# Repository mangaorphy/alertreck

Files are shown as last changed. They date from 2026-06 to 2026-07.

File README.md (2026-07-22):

# Alertreck

**Offline edge-AI system for anti-poaching audio detection on a Raspberry Pi 4.**
Alertreck listens continuously, detects gunshots, chainsaws, vehicles and human voices in real time,
and sends GPS-tagged alerts to rangers via GSM/SMS when a threat is confirmed; entirely offline, no
internet required.

It is also a comparative research study: **five models across four machine-learning paradigms** are
trained on the same data and benchmarked, then the best edge candidate is deployed with a live
**Grad-CAM explainability dashboard**.

<p align="center">
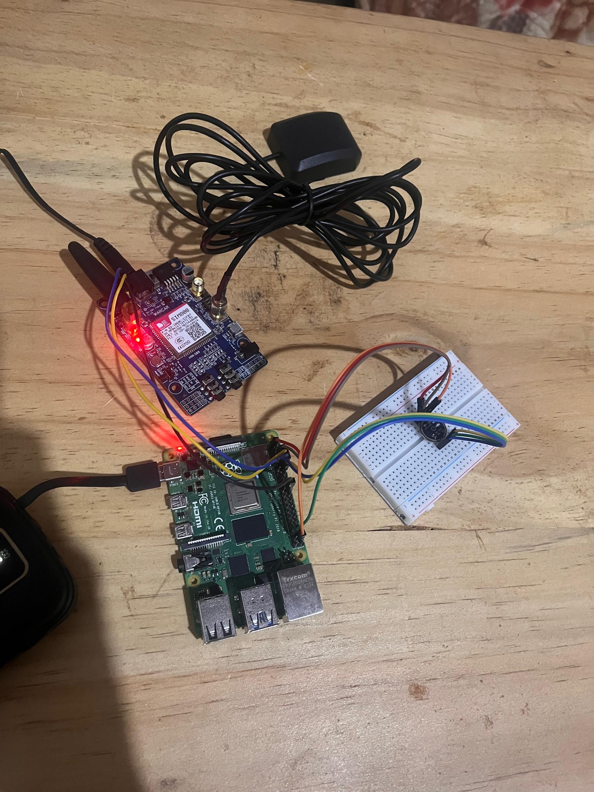
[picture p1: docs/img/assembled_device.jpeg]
Assembled Alertreck device — Raspberry Pi 4, INMP441 mic and SIM808 GSM/GPS in the enclosure
  
</p>

**Repository:** <https://github.com/mangaorphy/alertreck>

```bash
git clone https://github.com/mangaorphy/alertreck.git
```

---

## Demo Video

A full walkthrough of the system ; training, the edge device, live detection, and the Grad-CAM
dashboard:

### → **[Watch the Alertreck demo on Drive](https://drive.google.com/file/d/1CwxBU4wMTagHa2JpmVC7J57uuw0_VR09/view?usp=sharing)**

---

# Capstone Final Deliverable

> Demonstration of the planned functionalities under different testing strategies, with different data
> values, and across different hardware. Followed by analysis against the proposal, discussion of impact,
> and recommendations; prepared with supervisor **Hubert Apana**.
>
> **Jump to:** [Testing Results](#1-testing-results) · [Analysis](#2-analysis) ·
> [Discussion](#3-discussion) · [Recommendations](#4-recommendations) ·
---

## 1. Testing Results

The system was validated with three testing strategies and across two hardware tiers. Live footage of
everything below is in the **[demo video](https://drive.google.com/file/d/1CwxBU4wMTagHa2JpmVC7J57uuw0_VR09/view?usp=sharing)**.

### 1a. Functionality under different testing strategies

| Strategy | What it verifies | Artefact / command |
|---|---|---|
| **Unit testing** | Each module works in isolation ; mic capture, GPS fix, ONNX inference | `alertrack/deploy/test_i2s_mic.py`, `sensors/gps.py`, `inference/model.py` |
| **Integration testing** | Modules work together end-to-end ; capture → onset → mel → CNN → decision → SMS | `python3 -m alertrack.main` (full daemon) |
| **System / live testing** | Real acoustic events trigger real SMS alerts to a ranger phone | Live demo (video), dashboard at `:8000` |
| **Edge-case testing** | Behaviour at the margins ; low-SNR gunshot, pure background (no false alarm) | Live demo, Slide 9 of the demo script |

**Unit test ; microphone capture**

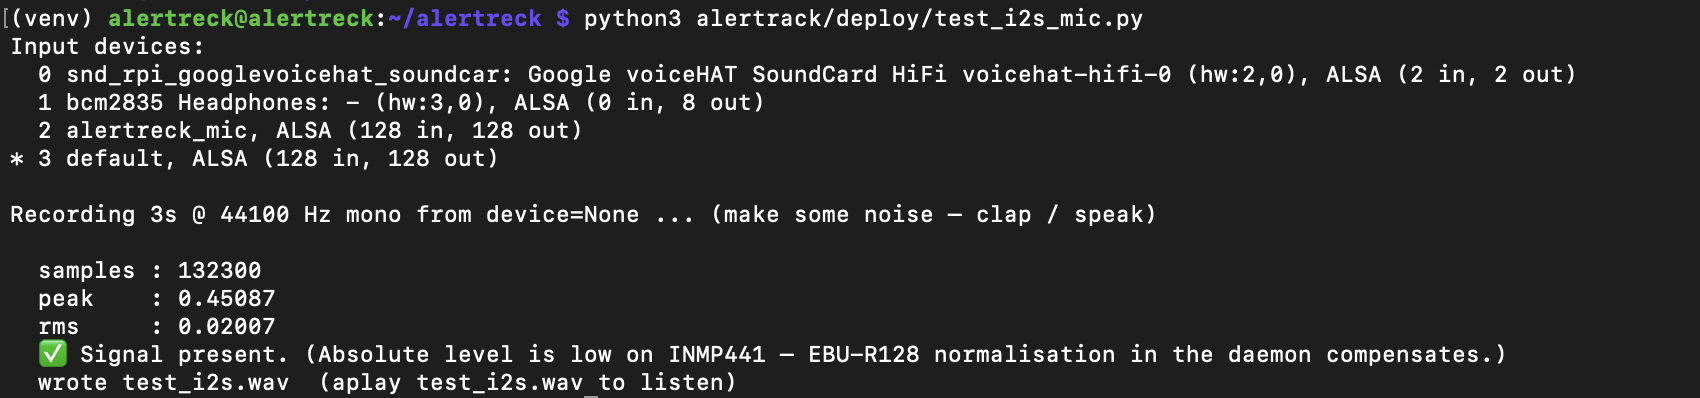
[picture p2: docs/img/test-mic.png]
Unit test ; mic capture

*Capture: terminal output of the I2S mic test showing `[PASS]` device + non-zero RMS rising on a clap vs near-zero on silence.*

**Integration test ; daemon startup + onset loop**

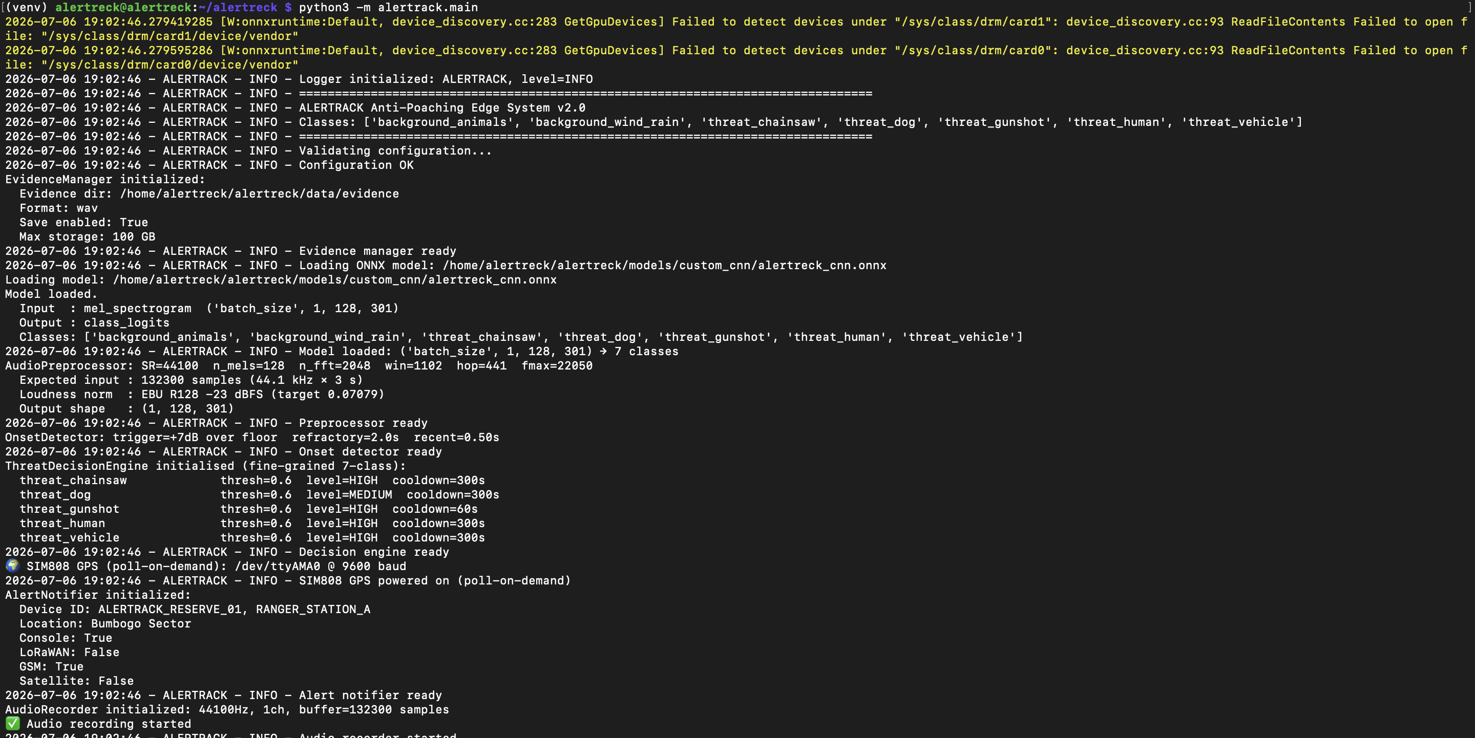
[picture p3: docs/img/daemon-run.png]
Daemon integration run

*Capture: `python3 -m alertrack.main` startup log (model loaded, onset detector ready, "System ready") followed by onset lines with non-zero RMS.*

**System test ; live threat → SMS**

<p align="center">
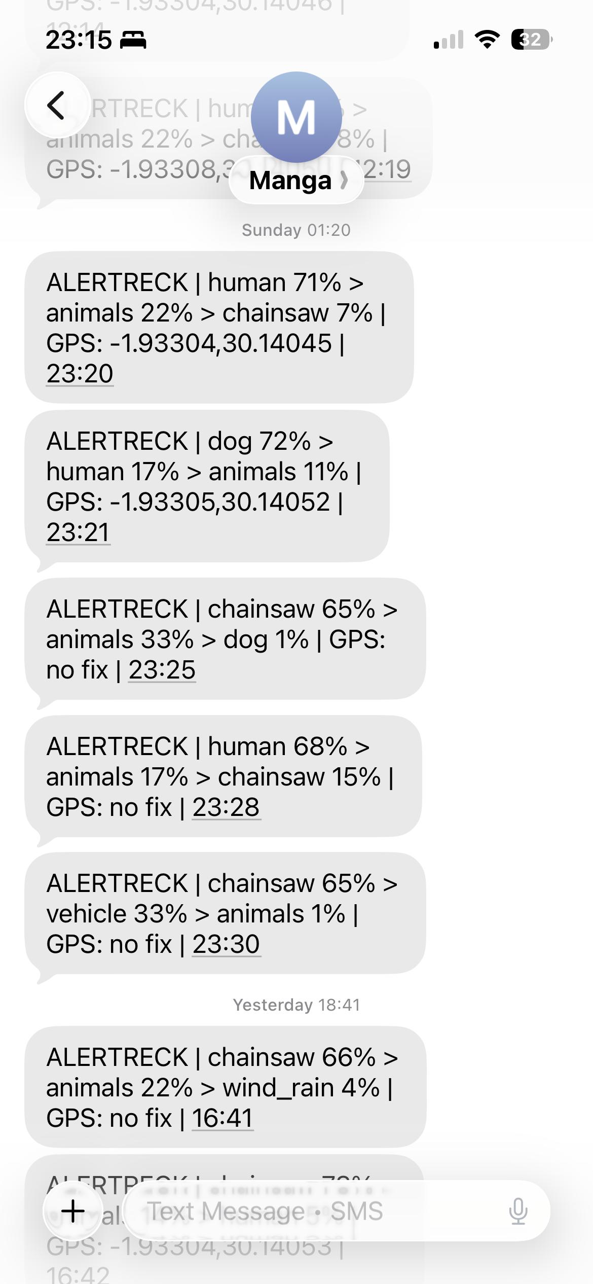
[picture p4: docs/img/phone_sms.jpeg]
Ranger phone receiving a GPS-tagged threat SMS alert from Alertreck
  
</p>

*A detected threat fires a GPS-tagged SMS to the ranger phone within seconds — class, confidence, coordinates, and timestamp.*

### 1b. Functionality with different data values

The model was exercised across **all 7 classes** ; the two background classes (must stay silent) and the
five threat classes (must each fire an independent, correctly-labelled alert).

| Input class | Expected behaviour | Result |
|---|---|---|
| `background_animals` | No alert | ignored |
| `background_wind_rain` | No alert | ignored |
| `threat_gunshot` | HIGH alert + SMS | fired (conf ≈ 0.87) |
| `threat_chainsaw` | HIGH alert + SMS | fired (conf ≈ 0.82) |
| `threat_human` | HIGH alert + SMS |fired (conf ≈ 0.91) |
| `threat_dog` | MEDIUM alert + SMS | fired |
| `threat_vehicle` | HIGH alert + SMS | weakest class (see Analysis) |

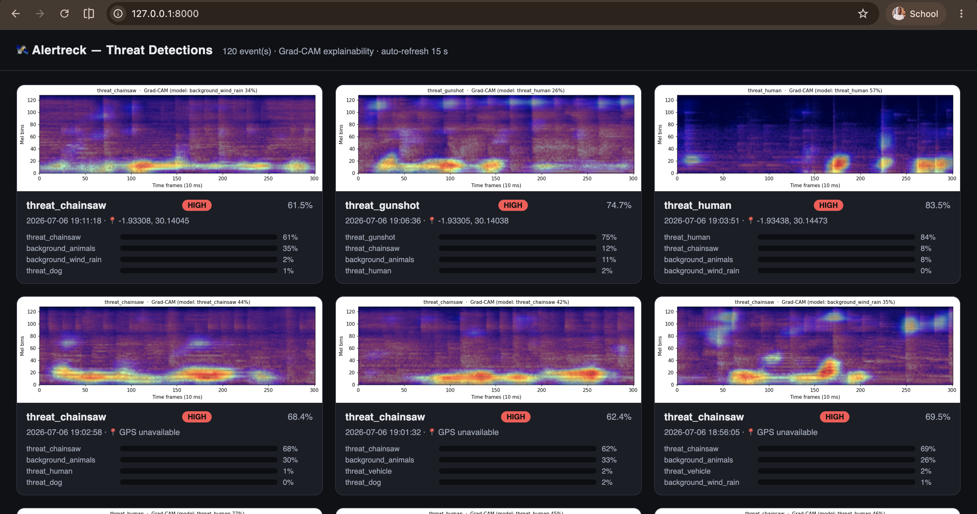
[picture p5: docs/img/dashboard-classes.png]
Dashboard ; multiple classes detected


*Different confidence values:* the decision engine applies a per-class threshold (0.60) ; clips below it
are suppressed, demonstrating the system responds to the **value** of the confidence, not just the class.

### 1c. Performance on different hardware / software

The same 4.6 MB ONNX graph trains on a cloud GPU and runs unmodified on the Pi 4 CPU.

| Metric | Training tier | Edge tier |
|---|---|---|
| Hardware | Kaggle **T4 GPU** | **Raspberry Pi 4** (4 GB), CPU-only |
| Software | Python 3.10, PyTorch 2.x, CUDA | Python 3, ONNX Runtime (no torch) |
| Role | ~4 h / model training | Real-time inference, ≤ 5 W |
| Model | PyTorch checkpoint | 4.6 MB ONNX (single graph) |
| Inference time | ; | **≤ 80 ms / 3 s window** (≈ real-time headroom) |

---

## 2. Analysis

*How the results measured against the objectives in the project proposal (with supervisor).*

### Research questions vs. outcomes

| RQ | Objective | Target | Achieved | Met? |
|---|---|---|---|---|
| **RQ1** | Edge CNN classifies 7 classes in real time on Pi 4 | usable macro-F1, real-time | Macro-F1 **0.807**, ≤80 ms, Pi 4 CPU | ✅ |
| **RQ2** | Few-shot ProtoNet matches supervised CNN | within noise | 0.804 vs 0.807 (Δ 0.003) | ✅tied |
| **RQ3** | Unsupervised anomaly detection flags threats without labels | useful AUC | Conv-AE AUC **0.805** | ⚠️ partial |
| **RQ4** | Detections are explainable | physically-plausible attribution | Grad-CAM on impulsive onset | ✅ |
| **RQ5** | Frozen W2V2 transfer beats task-trained CNN | W2V2 > CNN | 0.763 vs 0.807 | ❌ not supported |

### Per-class F1 (deployed CNN) ; against the 0.80 target

| Class | F1 | vs target |
|---|---|---|
| `threat_human` | 0.868 | ;✅ |
| `threat_chainsaw` | 0.824 | ;✅ |
| `threat_gunshot` | 0.815 | ;✅ |
| `background_*` | 0.830 | ;✅ low false-alarm rate |
| `threat_dog` | 0.794 | ⚠️ just under |
| `threat_vehicle` | 0.681 | ❌ missed (smallest class) |

### Objectives met / missed

- **Met:** real-time offline 7-class detection on a Pi 4; GPS-tagged SMS alerting; five-model
  comparison across four paradigms; live Grad-CAM explainability; gunshot (the priority threat)
  reliably detected (AUC ≈ 0.97).
- **Missed / partial:** **vehicle** F1 (0.681 vs 0.80 target) ; but its AUC is 0.97, so the class *is*
  separable and the gap is a **threshold-tuning** problem, not a modelling failure. 
- **Integrity note:** an earlier file-level split inflated every score to ≈ 0.92 via data leakage. After
  fixing it to a **group-aware split** (segments of one recording never span train/test), the honest
  numbers above are what is report.

---

## 3. Discussion

### Significance of the Milestones and Research Outcomes

This project demonstrates the feasibility of an affordable, offline edge-AI system for wildlife anti-poaching surveillance.Despite lower performance on vehicle sounds, the system achieved excellent discrimination for gunshots (AUC ≈ 0.97), the highest-priority threat class.

Several development milestones were fundamental to the validity and deployment of the system. Correcting data leakage during dataset preparation was the most significant milestone, ensuring that reported performance accurately reflected the model's generalisation ability. Implementing onset-triggered inference enabled continuous monitoring while maintaining low computational and power requirements, making long-term deployment on a Raspberry Pi practical. Exporting the model to ONNX further enabled seamless deployment from cloud-based training to edge-device inference without modification.

From a research perspective, the findings provide an important negative result. Contrary to the initial hypothesis, frozen Wav2Vec2 transfer learning did not outperform the task-specific CNN. Instead, the lightweight CNN achieved superior performance while requiring substantially fewer computational resources, suggesting that carefully trained compact models remain highly competitive for environmental threat detection.

From an engineering perspective, the comparable performance of the CNN and ProtoNet indicates that deployment decisions can be guided by computational efficiency rather than predictive accuracy alone. Given its small footprint (approximately 4.6 MB), self-contained architecture, and ease of deployment, the CNN represents the most practical solution for real-world edge-AI wildlife monitoring.

---

## 4. Recommendations

### Future Work and Practical Deployment

Several improvements can further enhance the performance and deployability of the proposed system. First, post-hoc threshold calibration should be performed for the vehicle class, as its high AUC (≈ 0.97) suggests that improved decision boundaries could increase classification performance without retraining the model. Second, the vehicle class should be expanded by collecting at least 1,000 additional audio samples to improve class balance and model generalisation.

From a deployment perspective, applying INT8 quantisation would reduce the model size from approximately 4.6 MB to 1.2 MB, enabling deployment on lower-cost hardware such as the Raspberry Pi Zero 2 W. For operational security, SMS alerts should be encrypted using secure communication protocols (e.g., AES-256 or DTLS) to protect sensitive GPS coordinates from interception. In addition, integrating solar power and supercapacitor-based energy storage would enable reliable long-term operation in remote, off-grid environments.

Finally, the system should be deployed through a community-centred model by publishing the hardware bill of materials (BOM), deployment guide, and maintenance procedures. This would facilitate replication by wildlife reserves and conservation organisations seeking an affordable, offline edge-AI solution for anti-poaching surveillance.

---

## Data, Dataset & Models

The raw audio, processed feature shards, and trained model artifacts are **too large for git** and live
in Google Drive:

### → **[Alertreck Data, Dataset & Models (Google Drive)](https://drive.google.com/drive/folders/1U9BwIUNQ8Snl5RxR8LHthWfdOc_EdcTM?usp=sharing)**

| Folder | Place into | Contents |
|---|---|---|
| `dataset/` | `./dataset/` | Raw audio, 7 class folders (11,333 files) |
| `data/processed/` | `./data/processed/` | Mel / MFCC shards, W2V2 embeddings, `splits.json`, `manifest.json` |
| `models/` | `./models/` | Trained checkpoints, ONNX exports, `results.json` per model |

Download these and drop them into the matching paths at the repo root to run training, evaluation, the
report notebook, or the dashboard.

---

## Overview

| Paradigm | Model | Notebook | Role |
|---|---|---|---|
| Supervised classification | Custom CNN | `03a-train-cnn` | **Deployed** (edge) |
| Few-shot metric learning | Prototypical Network | `03b-train-protonet` | Accuracy benchmark |
| Transfer learning (frozen) | Wav2Vec2-L2 | `04a-train-w2v2-l2` | Benchmark |
| Unsupervised anomaly detection | Convolutional Autoencoder | `04b-train-conv-ae` | Anomaly detector (best of the two) |
| Classical anomaly detection | One-Class SVM | `04c-train-oc-svm` | Confirmatory (lightest) |

---

## Hardware

| Component | Spec |
|---|---|
| Edge device | Raspberry Pi 4 (4 GB) |
| Microphone | INMP441 I2S MEMS mic (digital, no analog hum) |
| Alert module | SIM808 GSM/GPS over UART |
| Deployment | Offline-first; SMS/GPRS alert with GPS coordinates |

### System architecture

<p align="center">
  Alertreck system architecture — audio capture, onset detection, CNN inference, decision engine, and GSM/GPS alerting
</p>

---

## Dataset

7 audio classes, 44.1 kHz. Raw clips are **variable length** (~0.6–12 s, median ≈ 5 s) — impulsive
classes (gunshot, dog) are short, continuous classes (chainsaw, wind/rain) are longer. During
preprocessing every clip is standardized into **3-second analysis windows** (44.1 kHz mono) for both
training and edge inference. Background classes never alert; threat classes (2–6) trigger alerts.

| Label | Class | Category | Raw files | Audio (hrs) |
|---|---|---|---|---|
| 0 | `background_animals` | Background | 2,139 | 3.66 |
| 1 | `background_wind_rain` | Background | 2,000 | 4.58 |
| 2 | `threat_chainsaw` | Threat | 568 | 1.43 |
| 3 | `threat_dog` | Threat | 1,040 | 0.93 |
| 4 | `threat_gunshot` | Threat | 3,304 | 3.38 |
| 5 | `threat_human` | Threat | 1,242 | 2.33 |
| 6 | `threat_vehicle` | Threat | 1,040 | 1.15 |
| | **Total** | | **11,333** | **≈ 17.5** |

*Total ≈ **17.5 hours** of raw audio. Durations measured with `soundfile`; 33 corrupt/unreadable files
(all `threat_chainsaw`) are excluded from the hour totals.*

Feature extraction, the group-aware 60/20/20 split (split by parent recording to prevent leakage), and
the three-phase augmentation curriculum are documented in
**[docs/AUDIO_PREPROCESSING.md](docs/AUDIO_PREPROCESSING.md)**.

---

## Project Structure

```
alertreck/
├── dataset/                       # Raw audio (7 class folders)            ── from Drive
├── data/processed/                # Mel/MFCC shards, W2V2 embeddings        ── from Drive
│   ├── mel/   {train, val, test, train_aug_A/B/C}/  shard_NNN.npz
│   ├── mfcc/  {same}/                                shard_NNN.npz
│   ├── w2v2_l2/                    # 768-dim L2-normalised embeddings
│   ├── splits.json                # Group-aware 60/20/20 by parent recording (seed 42)
│   └── manifest.json              # Full run parameters + script SHA256
├── notebooks/
│   ├── 00-model-report.ipynb      # Consolidated report: data viz + all metrics + Grad-CAM
│   ├── 02b-prepare-w2v2-embeddings.ipynb
│   ├── 03a-train-cnn.ipynb        ├ 03b-train-protonet.ipynb
│   ├── 04a-train-w2v2-l2.ipynb    ├ 04b-train-conv-ae.ipynb
│   └── 04c-train-oc-svm.ipynb
├── scripts/
│   ├── audio_preprocessing.py     # Mel/MFCC shards + augmentation curriculum
│   ├── prepare_w2v2_embeddings.py # W2V2 embedding extraction
│   ├── export_model.py            # PyTorch → ONNX (CNN, 301-frame, dynamic width)
│   ├── data_manifest.py  ├ data_loader.py
├── models/                        # Checkpoints, ONNX, results.json         ── from Drive
│   └── {custom_cnn, protonet, w2v2_l2, conv_ae, oc_svm}/
├── alertrack/                     # Raspberry Pi edge service
│   ├── main.py                    # Onset-triggered inference loop
│   ├── audio/{recorder,preprocess,onset}.py
│   ├── inference/{model,decision}.py
│   ├── sensors/gps.py  ├ alerts/notifier.py  ├ storage/{evidence,logger}.py
│   ├── config.py  └ alertrack.service        # systemd unit
├── dashboard/                     # Grad-CAM explainability dashboard (Flask, runs on a Mac)
│   ├── app.py  ├ gradcam.py  ├ templates/index.html
│   ├── sync_events.sh  └ README.md
├── docs/                          # Full documentation (see below)
└── README.md
```

---

## Pipeline

### 1. Preprocess (local)
```bash
python3 scripts/audio_preprocessing.py --aug-phase A B C
```
Writes mel + MFCC shards to `data/processed/`. Upload to Kaggle as `alertreck-mel2` / `alertreck-mfcc`.

### 2. W2V2 embeddings (Kaggle GPU, ~2 h)
Run `02b-prepare-w2v2-embeddings.ipynb`; upload the output as the `w2v2-embeddings` dataset.

### 3. Train (Kaggle GPU)
Run `03a → 03b → 04a → 04b → 04c`. Each saves `results.json` + an ONNX/joblib model.

### 4. Export for the edge
```bash
/opt/anaconda3/bin/python scripts/export_model.py \
  --model models/custom_cnn/best_model.pt --out models/custom_cnn/alertreck_cnn.onnx
```

### 5. Deploy to the Pi
Full runbook ; flashing, mic calibration, onset tuning, GSM/GPS ; in
**[docs/DEPLOYMENT.md](docs/DEPLOYMENT.md)**.

---

## Results

Numbers below are on the **leak-free group-aware split** (an earlier file-level split inflated every
score to ≈ 0.92; those figures are retired).

| Model | Test Acc | Macro F1 | AUC | Gunshot | Edge-ready |
|---|---|---|---|---|---|
| **CNN (deployed)** | **0.8263** | **0.8069** | **0.9757** | F1 0.815 | ;✅ **best** |
| ProtoNet | 0.8241 | 0.8036 | 0.9748 | F1 **0.843** | ;✅ |
| Wav2Vec2-L2 | 0.7806 | 0.7626 | 0.9605 | F1 0.812 | ⚠️ (truncated encoder) |
| Conv-AE (binary) | 0.51 | ; | **0.8050** | AUC **0.839** | ⚠️ |
| OC-SVM (binary) | 0.51 | ; | 0.7192 | AUC 0.627 | ; |

The two task-trained classifiers (**CNN ≈ ProtoNet**) are statistically tied at the top; the
frozen-transfer **Wav2Vec2-L2** trails ; the RQ5 result that out-of-species transfer extends to threat
sounds but does not overtake supervised learning. The **CNN is both the most accurate and the deployed
model** (smallest, self-contained, real-time on a Pi 4 CPU). **Vehicle** is the hardest class; gunshot
is reliably detected (AUC ≈ 0.97) by all three. Among the anomaly detectors the AUC-selected **Conv-AE**
(binary AUC 0.805) beats the classical **OC-SVM** (0.719) ; though OC-SVM is far lighter. Full
analysis: **[docs/MODEL_COMPARISON.md](docs/MODEL_COMPARISON.md)**.

**[notebooks/00-model-report.ipynb](notebooks/00-model-report.ipynb)** ; class
distributions, all-model metrics, and Grad-CAM.

---

## Edge System (`alertrack/`)

The deployed daemon runs a fast ONNX CNN with field-hardened audio handling:

- **Onset-triggered inference** ; classifies the 3 s window around a detected energy onset (adaptive
  noise floor), instead of a blind timer: fewer false positives, less CPU, event centred in the window.
- **Train/serve-consistent preprocessing** ; EBU R128 loudness + `win_length=1102` + 301 frames,
  matching training exactly. (A 50/60 Hz mains-hum high-pass remains from the USB-mic era; the INMP441
  I2S mic is digital and carries no analog hum, so it is now largely redundant.)
- **Decision engine** ; per-class thresholds, alert levels (HIGH/MEDIUM), independent cooldowns.
- **Alerting** ; SIM808 GSM/SMS with GPS coordinates; audio + metadata evidence saved per detection.
- **Resilience** ; `systemd` auto-restart, mic/GPS reconnect, storage limits.

---

## Explainability Dashboard (`dashboard/`)

A Flask LAN dashboard showing each detected sound with a **Grad-CAM** heatmap over its mel spectrogram ;
*why* the CNN flagged it. Runs on a separate machine where PyTorch lives, so the Pi stays
ONNX-only; it auto-syncs detections from the Pi and refreshes itself. See
**[dashboard/README.md](dashboard/README.md)**.

```bash
cd dashboard && /opt/anaconda3/bin/python app.py    # → http://<mac-ip>:8000
```

---

## Documentation

- [ROADMAP.md](docs/ROADMAP.md) ; milestones and research questions
- [Alertreck_Proposal_Updated.pdf](Alertreck_Proposal_Updated.pdf) ;  project proposal
- [DESIGN.md](docs/DESIGN.md) ; system architecture
- [MODEL_DESIGN.md](docs/MODEL_DESIGN.md) ; model specifications
- [AUDIO_PREPROCESSING.md](docs/AUDIO_PREPROCESSING.md) ; feature extraction + augmentation curriculum
- [MODEL_COMPARISON.md](docs/MODEL_COMPARISON.md) ; comparative results and model selection
- [DEPLOYMENT.md](docs/DEPLOYMENT.md) ; Raspberry Pi deployment runbook
- [dashboard/README.md](dashboard/README.md) ; Grad-CAM dashboard

---

## Requirements

Training runs on Kaggle (Python 3.10, PyTorch 2.x, CUDA). Edge inference runs on a Raspberry Pi 4 with
ONNX Runtime (CPU) ; no torch on the Pi. The Grad-CAM dashboard needs torch, on the Mac only.

```
# Training / dashboard (Mac/Kaggle):  torch transformers scikit-learn librosa soundfile
#                                      onnxruntime joblib tqdm matplotlib flask
# Edge (Raspberry Pi):                 numpy librosa sounddevice soundfile onnxruntime pyserial psutil
```

---

*Capstone project ; African Leadership University, 2025–2026.*
*Large artifacts (dataset, processed data, models): [Google Drive](https://drive.google.com/drive/folders/1U9BwIUNQ8Snl5RxR8LHthWfdOc_EdcTM?usp=sharing).*

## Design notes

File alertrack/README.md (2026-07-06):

# ALERTRACK - Anti-Poaching Edge System

**Offline-first, AI-powered threat detection system for wildlife conservation**

## 🎯 Overview

ALERTRACK is a production-ready edge ML system designed to run 24/7 on Raspberry Pi devices in remote wildlife areas. It uses audio classification to detect poaching threats (gunshots, chainsaws, vehicles) in real-time and triggers immediate alerts.

### Key Features

- ✅ **Fully Offline**: No internet required - runs completely on device
- ✅ **Real-time Detection**: Continuous audio monitoring with rolling buffer
- ✅ **High Accuracy**: deployed CNN — 0.826 test accuracy / 0.807 macro-F1 (leak-free group-aware split)
- ✅ **Fault Tolerant**: Auto-reconnect on hardware failures, never crashes
- ✅ **GPS Integration**: Precise threat location for rapid response
- ✅ **Evidence Collection**: Saves audio clips for retraining and verification
- ✅ **Smart Cooldown**: Prevents alert spam while maintaining sensitivity
- ✅ **Multi-channel Alerts**: Console, disk, LoRaWAN, GSM, Satellite (extensible)

## 📊 Threat Classification

| Class | Type | Threshold | Examples |
|---|---|---|---|
| **THREAT** | High Priority | ≥ 85% | Gunshot, Chainsaw, Vehicle Engine, Human Voice |
| **THREAT_CONTEXT** | Medium Priority | ≥ 75% | Dog Bark |
| **BACKGROUND** | No Alert | N/A | Animal Sounds, Wind/Rain, Ambient Noise |

## 🛠️ Hardware

### Prototype BOM (≤ USD 80)
- **Raspberry Pi 4 Model B** — 2 GB RAM, quad-core ARM Cortex-A72 @ 1.8 GHz; edge AI inference + alert dispatch
- **INMP441 I2S MEMS microphone** — digital I2S (no analog hum), 60 Hz–15 kHz; captured at 48 kHz and resampled to 44.1 kHz. Wiring + ALSA setup: [deploy/INMP441_SETUP.md](deploy/INMP441_SETUP.md)
- **SIM808 GSM/GPRS/GPS module** — UART serial, built-in GPS receiver; SMS alerts (MTN/Airtel Rwanda) + device GPS coordinates; no data plan required
- **32 GB Class 10 MicroSD card** — OS, model weights, SQLite event database, evidence audio
- **Rwanda SIM card** (MTN or Airtel) — prepaid, GSM only; inserted into SIM808

### Optional Upgrades
- **Solar panel + LiPo battery** (for remote off-grid deployment)
- **Weatherproof enclosure** (IP65+, outdoor mounting)
- **Camera module** (visual verification — stub implemented)

## 📁 Project Structure

```
alertrack/
├── main.py                 # Main entry point and system integration
├── config.py               # Central configuration
├── utils.py                # Common utilities
├── requirements.txt        # Python dependencies
├── README.md              # This file
│
├── audio/                 # Audio processing
│   ├── recorder.py        # Continuous audio capture with rolling buffer
│   └── preprocess.py      # Mel spectrogram generation
│
├── inference/             # Machine learning
│   ├── model.py          # TFLite model loading and inference
│   └── decision.py       # Threat thresholding and cooldown logic
│
├── sensors/              # Hardware sensors
│   └── gps.py           # GPS coordinate reading (NMEA parsing)
│
├── alerts/               # Notification system
│   └── notifier.py      # Multi-channel alert dispatch
│
└── storage/              # Data persistence
    ├── logger.py         # System logging with rotation
    └── evidence.py       # Audio evidence storage and management
```

## 🚀 Installation

### 1. Prepare Raspberry Pi

```bash
# Update system
sudo apt update && sudo apt upgrade -y

# Install system dependencies
sudo apt install -y python3-pip python3-venv portaudio19-dev libsndfile1

# Install optional tools
sudo apt install -y git vim htop
```

### 2. Clone/Copy Project

```bash
# Copy project to Raspberry Pi
scp -r alertrack/ pi@raspberrypi.local:~/

# Or clone from repository
git clone <your-repo-url> ~/alertrack
cd ~/alertrack
```

### 3. Create Virtual Environment

```bash
cd ~/alertrack
python3 -m venv venv
source venv/bin/activate
```

### 4. Install Python Dependencies

```bash
# Install TFLite Runtime (Raspberry Pi optimized)
pip install --index-url https://google-coral.github.io/py-repo/ tflite_runtime

# Install other dependencies
pip install -r requirements.txt
```

### 5. Add Model Files

```bash
# Create models directory
mkdir -p models

# Copy your trained .tflite model
# Example: yamnet_classifier.tflite, threat_detection_custom_cnn.tflite, etc.
scp your_model.tflite pi@raspberrypi.local:~/alertrack/models/
```

### 6. Configure GPS (if using)

```bash
# Find GPS device
ls /dev/ttyUSB* /dev/ttyACM*

# Test GPS connection
cat /dev/ttyUSB0  # Should see NMEA sentences ($GPGGA, $GPRMC, etc.)

# Edit config.py to set correct GPS port
nano config.py
# Set: GPS_PORT = "/dev/ttyUSB0"
```

## ⚙️ Configuration

Edit [config.py](config.py) to customize:

```python
# Model selection
MODEL_PATH = "models/yamnet_classifier.tflite"  # or custom_cnn, mobilenet

# Device identification
DEVICE_ID = "ALERTRACK-001"
DEVICE_LOCATION = "Serengeti National Park, Zone A"

# Threat thresholds
THREAT_THRESHOLD = 0.85          # 85% confidence for THREAT
THREAT_CONTEXT_THRESHOLD = 0.75  # 75% for THREAT_CONTEXT

# Cooldown (prevent alert spam)
COOLDOWN_SECONDS = 300  # 5 minutes per threat type

# GPS
ENABLE_GPS = True
GPS_PORT = "/dev/ttyUSB0"
SIMULATE_GPS = False  # Set True for testing without GPS hardware

# Storage limits
MAX_EVIDENCE_STORAGE_GB = 100  # Auto-cleanup when exceeded
ALERT_RETENTION_DAYS = 90      # Delete evidence older than 90 days
```

## 🎮 Running the System

### Manual Start (Testing)

```bash
cd ~/alertrack
source venv/bin/activate
python main.py
```

### Auto-start on Boot (Production)

```bash
# Copy systemd service file
sudo cp alertrack.service /etc/systemd/system/

# Edit service to set correct paths
sudo nano /etc/systemd/system/alertrack.service

# Enable and start service
sudo systemctl enable alertrack.service
sudo systemctl start alertrack.service

# Check status
sudo systemctl status alertrack.service

# View logs
sudo journalctl -u alertrack -f
```

### Stop the System

```bash
# If running manually: Ctrl+C

# If running as service:
sudo systemctl stop alertrack.service
```

## 📋 System Logs

Logs are saved to `logs/alertrack.log` with automatic rotation (10 MB max, 5 backups).

```bash
# View live logs
tail -f logs/alertrack.log

# View service logs
sudo journalctl -u alertrack -f
```

## 🚨 Alerts

Alerts are saved to `alerts/` directory as JSON files:

```json
{
  "alert_id": "abc123...",
  "timestamp": "2024-01-15T14:30:45Z",
  "device_id": "ALERTRACK-001",
  "threat_type": "gunshot",
  "threat_level": "HIGH",
  "confidence": 0.94,
  "latitude": -2.1534,
  "longitude": 34.6857,
  "audio_evidence": "evidence/2024-01-15/gunshot/gunshot_143045.wav"
}
```

## 📦 Evidence Storage

Audio clips are organized by date and threat type:

```
evidence/
├── 2024-01-15/
│   ├── gunshot/
│   │   ├── gunshot_143045.wav
│   │   └── gunshot_151230.wav
│   └── chainsaw/
│       └── chainsaw_160015.wav
└── 2024-01-16/
    └── vehicle_engine/
        └── vehicle_160530.wav
```

## 🧪 Testing Individual Modules

Each module includes standalone test functions:

```bash
# Test audio recorder
python -m audio.recorder

# Test GPS reader
python -m sensors.gps

# Test model inference
python -m inference.model

# Test preprocessor
python -m audio.preprocess
```

## 🔧 Troubleshooting

### Audio Issues

```bash
# List available microphones
python -c "import sounddevice as sd; print(sd.query_devices())"

# Test microphone
arecord -l  # List devices
arecord -D plughw:1,0 -d 5 test.wav  # Record 5 seconds
aplay test.wav  # Playback
```

### GPS Issues

```bash
# Check GPS device connection
ls /dev/ttyUSB* /dev/ttyACM*

# Read raw NMEA sentences
cat /dev/ttyUSB0

# Check permissions
sudo usermod -a -G dialout $USER
# Logout and login again

# Test with simulation mode
# In config.py: SIMULATE_GPS = True
```

### Model Issues

```bash
# Verify model file exists
ls -lh models/*.tflite

# Test model loading
python -c "from inference.model import TFLiteModel; m = TFLiteModel('models/your_model.tflite'); print(m.get_model_info())"
```

### Performance Issues

```bash
# Check CPU/Memory usage
htop

# Monitor inference time (should be < 2 seconds)
# Watch logs for warnings: "Inference took X.XXs"

# Reduce inference frequency if needed
# In config.py: INFERENCE_INTERVAL = 5.0  # seconds
```

## 📊 Performance Metrics

- **Inference Time**: ~0.5-1.5s on Raspberry Pi 4 (TFLite optimized)
- **Memory Usage**: ~300-500 MB
- **CPU Usage**: ~30-50% (single core)
- **Storage**: ~10-50 MB per day (depends on threat frequency)

## 🔐 Security Considerations

- **Offline Operation**: No network connectivity required (prevents hacking)
- **Evidence Integrity**: WAV files saved with timestamps and metadata
- **Access Control**: Run as non-root user, use systemd for isolation
- **Data Retention**: Automatic cleanup prevents disk overflow

## 🛣️ Roadmap

- [x] Core audio classification pipeline
- [x] GPS integration
- [x] Evidence storage and management
- [x] Cooldown logic
- [ ] LoRaWAN alert transmission
- [ ] GSM/SMS alert transmission
- [ ] Satellite communication (Iridium, Globalstar)
- [ ] Camera integration for visual verification
- [ ] Multi-device mesh network
- [ ] Web dashboard for fleet management

## 📄 License

[Your License Here]

## 🤝 Contributing

[Your Contribution Guidelines]

## 📞 Support

For issues or questions:
- Email: [your-email]
- GitHub Issues: [your-repo-url]

---

**Built with ❤️ for wildlife conservation**

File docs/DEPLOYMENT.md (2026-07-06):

# ALERTRACK  Raspberry Pi Deployment Guide

---

## Part 1  Flash a Fresh SD Card

**On your Mac:**

1. Download **Raspberry Pi Imager** from [raspberrypi.com/software](https://www.raspberrypi.com/software/)
2. Insert SD card (16 GB minimum, 32 GB recommended)
3. Open Imager → **Choose OS** → `Raspberry Pi OS Lite (64-bit)` (no desktop needed)
4. **Before writing**  click the gear icon (⚙️) and configure:
   - Enable SSH ✓
   - Set username: `alertreck` / password: (your choice  avoid special characters)
   - Set Wi-Fi SSID + password (your hotspot or router)
   - **Set Wi-Fi country** (e.g. `RW`)  without it the radio stays disabled and the Pi never joins
   - Set hostname: `alertreck`
5. Click **Write** and wait

---

## Part 2  Find the Pi's IP Address

After inserting the SD card and booting the Pi, wait ~60 seconds then try one of these:

**Option A  mDNS hostname (easiest):**
```bash
ping alertreck.local
```
The IP will show in the response, e.g. `64 bytes from 192.168.1.88`

**Option B  Scan the network:**
```bash
# Install nmap if needed: brew install nmap
nmap -sn 192.168.1.0/24 | grep -i raspberry
```
> Replace `192.168.1` with your actual prefix. Check yours with: `ipconfig getifaddr en0`

**Option C  From your router:**
Log into your router admin page (usually `192.168.1.1`) → connected devices → look for `alertreck`

**Option D  Connect a monitor and run:**
```bash
hostname -I
```

---

## Part 3  SSH into the Pi

```bash
ssh alertreck@alertreck.local
# or use the IP directly (changes on DHCP reboot  prefer the hostname above)
ssh alertreck@192.168.1.88
```

**First connection only**  type `yes` when asked about authenticity.

Username: `alertreck`  ·  Password: whatever you set in the Imager.

> Modern Raspberry Pi OS (Bookworm) has **no default `pi` user**  the account is the username
> you set when flashing. If SSH says "Permission denied", you are almost certainly using the wrong
> username (not the wrong password); SSH prompts for a password even when the user doesn't exist.

**SSH refused?** SSH was not enabled during flashing. Fix from your Mac:
```bash
touch /Volumes/bootfs/ssh
```
Eject, reinsert SD card into Pi, reboot.

**Set up a `ssh alertreck` alias + passwordless login (one-time, recommended):**
```bash
# On your Mac  add the alias to ~/.ssh/config
cat >> ~/.ssh/config <<'EOF'

Host alertreck
    HostName alertreck.local
    User alertreck
    StrictHostKeyChecking accept-new
EOF

# Copy your key so you never type the password again (asks for it once)
ssh-copy-id alertreck
ssh alertreck 'echo connected'    # should print "connected" with no prompt
```
> **After a reflash** the Pi gets a new SSH identity. Clear the stale key first or SSH will refuse:
> `ssh-keygen -R alertreck.local && ssh-keygen -R <old-ip>`, then `ssh-copy-id alertreck` again.

---

## Part 4  Set Up the Pi Environment

Run these commands **on the Pi** (inside the SSH session):

```bash
# Update system
sudo apt update && sudo apt upgrade -y

# Install system dependencies
sudo apt install -y python3-pip python3-venv ffmpeg git libportaudio2 libsndfile1

# Create project folder
mkdir -p ~/alertreck/models/custom_cnn
cd ~/alertreck

# Create Python virtual environment
python3 -m venv venv
source venv/bin/activate

# Install Python dependencies
pip install numpy librosa sounddevice soundfile onnxruntime pyserial psutil
```

---

## Part 5  Export & Deploy the Model

**On your Mac**, run from inside the `alertreck` project folder.

>**Don't have the trained model?** The checkpoints, ONNX exports, and `results.json` are on
> Google Drive: [Alertreck Data, Dataset & Models](https://drive.google.com/drive/folders/1U9BwIUNQ8Snl5RxR8LHthWfdOc_EdcTM?usp=sharing).
> Download `models/custom_cnn/` to skip training and go straight to deployment.

> **Environment:** the export needs `torch` + `onnx` + `onnxruntime`. These live in the **base**
> conda env (`/opt/anaconda3/bin/python`), *not* the `alertreck` env (which only has the runtime
> deps librosa/numpy). Use the base interpreter for export.
>
> **Checkpoint path:** the trained checkpoint is `models/custom_cnn/best_model.pt`. The script
> defaults to `models/best_model.pt`, so you **must** pass `--model` explicitly or it will fail
> with "model not found".

```bash
# Step 1  Export the trained PyTorch checkpoint to ONNX (traces at 301 frames, dynamic width)
/opt/anaconda3/bin/python scripts/export_model.py \
  --model models/custom_cnn/best_model.pt \
  --out   models/custom_cnn/alertreck_cnn.onnx
# Expect: "ONNX validation OK  output shape: (1, 7)"
# Output : models/custom_cnn/alertreck_cnn.onnx
#          input mel_spec = [batch, 1, 128, frames]  (frames dynamic; training shape = 301)

# Step 2  Copy the model to the Pi
scp models/custom_cnn/alertreck_cnn.onnx alertreck@alertreck.local:~/alertreck/models/custom_cnn/

# Step 3  Copy the daemon code to the Pi
rsync -av --exclude='__pycache__' alertrack/ alertreck@alertreck.local:~/alertreck/alertrack/
```

> **Verify the export (optional but recommended)** before copying:
> ```bash
> /opt/anaconda3/bin/python -c "import onnxruntime as ort, numpy as np; \
> s=ort.InferenceSession('models/custom_cnn/alertreck_cnn.onnx'); i=s.get_inputs()[0]; \
> print(i.name, i.shape); \
> print('301 OK', s.run(None,{i.name:np.random.randn(1,1,128,301).astype(np.float32)})[0].shape)"
> ```
> Should print `mel_spec ['batch', 1, 128, 'frames']` and `301 OK (1, 7)`.

---

## Part 6  Test the System on the Pi

```bash
# SSH into the Pi
ssh alertreck@alertreck.local

cd ~/alertreck
source venv/bin/activate

# Test model loads correctly
python3 -c "from alertrack.inference.model import ONNXModel; ONNXModel()"

# Test audio preprocessor
python3 -c "from alertrack.audio.preprocess import test_preprocessor; test_preprocessor()"

# Run the full system (Ctrl+C to stop).
# Must run as a module (-m) from ~/alertreck  main.py uses package-relative imports,
# so `python3 alertrack/main.py` fails with "attempted relative import with no known parent package".
python3 -m alertrack.main
```

> Run with `ALERTRACK_DEBUG=true python3 -m alertrack.main` to print the predicted class +
> confidence and the raw RMS every inference cycle  essential for the calibration in Part 6A.

---

## Part 6A  Microphone Setup & Calibration (INMP441 I2S)

The mic is the single biggest source of wrong predictions. Alertreck uses the **INMP441 I2S MEMS**
microphone  a digital mic on the Pi's I2S bus: no USB, no analog gain control, and no mains hum.

### 1. Wire it and enable I2S
Full wiring table, `config.txt` overlay, and the ALSA config are in
**[../alertrack/deploy/INMP441_SETUP.md](../alertrack/deploy/INMP441_SETUP.md)**. In short:

- Wire VDD→3V3, GND→GND, SCK→GPIO18, WS→GPIO19, SD→GPIO20, L/R→GND (left channel). **3.3 V only.**
- Add to `/boot/firmware/config.txt`: `dtparam=i2s=on` and `dtoverlay=googlevoicehat-soundcard`, then reboot.
- `sudo cp alertrack/deploy/asound.conf /etc/asound.conf` so the mic is the ALSA **default**
  (resampled 48→44.1 kHz, downmixed to mono).
- `config.py` already has `MIC_DEVICE_INDEX = None` (use the ALSA default).

Confirm the mic card and the SIM808 UART both came up:
```bash
arecord -l            # card "sndrpigooglevoi"
ls -l /dev/ttyAMA0    # SIM808 UART
```

### 2. Verify capture and level
The INMP441 is a quiet mic  that is expected. EBU-R128 normalisation rescales loudness before the
model, so the absolute level does not need tuning (there is no gain control). Just confirm it is alive:
```bash
# on the Pi: record 5 s (clap/speak during it), then check the level
arecord -D default -f S16_LE -r 44100 -c 1 -d 5 /tmp/cal.wav
python3 alertrack/deploy/test_i2s_mic.py        # prints peak / rms, writes test_i2s.wav
```
A working mic shows `peak`/`rms` clearly rising on sound and near-zero on silence. The measured ambient
floor is ≈ 0.0003 and real events ≈ 0.02.

### 3. Onset / silence thresholds (already calibrated for the INMP441)
Because the INMP441 is quieter than the old USB mic, the absolute energy gates in `config.py` were
lowered to match its noise floor (the old `0.01` sat *above* real events on this mic and silenced them):
```python
SILENCE_THRESHOLD = 0.0015   # skip inference below this raw RMS  (floor ~= 0.0003, events ~= 0.02)
ONSET_MIN_RMS     = 0.0015   # onset never fires below this absolute floor
ONSET_TRIGGER_DB  = 7.0      # relative gate over the adaptive floor (mic-agnostic, unchanged)
```
Nudge `0.0015` up toward `0.002` if idle silence ever triggers, or down to `0.001` if faint/distant
events are missed. To recalibrate from scratch, record ~10 s of true silence and set the gate a few×
above the measured per-frame floor.

> **No mains hum.** The INMP441 is digital, so the 50/60 Hz mains hum that plagued the USB mic is gone
>  along with the USB-power-isolator / powered-hub workarounds it required. The `HPF_CUTOFF_HZ`
> high-pass in `config.py` is now largely redundant (it still harmlessly removes wind rumble); set
> `HPF_ENABLED = False` and compare field detections if you prefer.

---

## Part 7  Enable Auto-Start on Boot

The service file (`alertrack/alertrack.service`) is already configured for the `alertreck` user,
the `/home/alertreck/alertreck` project path, and the `-m alertrack.main` module entrypoint 
no editing needed. Just install and enable it:

```bash
# On the Pi  install the systemd service
sudo cp ~/alertreck/alertrack/alertrack.service /etc/systemd/system/

sudo systemctl daemon-reload
sudo systemctl enable alertrack
sudo systemctl start alertrack

# Verify it is running
sudo systemctl status alertrack
```

> If you edit the daemon code later, re-`rsync` from the Mac then
> `sudo systemctl restart alertrack`. If you change `alertrack.service` itself,
> re-copy it and run `sudo systemctl daemon-reload` before restarting.

---

## Part 8  Common Commands

| Task | Command (on Pi) |
|---|---|
| Check system status | `sudo systemctl status alertrack` |
| Watch live logs | `journalctl -u alertrack -f` |
| Restart after code update | `sudo systemctl restart alertrack` |
| Stop the system | `sudo systemctl stop alertrack` |
| Disable auto-start | `sudo systemctl disable alertrack` |

| Task | Command (on Mac) |
|---|---|
| Update model on Pi | `scp models/custom_cnn/alertreck_cnn.onnx alertreck@alertreck.local:~/alertreck/models/custom_cnn/` |
| Update daemon code | `rsync -av --exclude='__pycache__' alertrack/ alertreck@alertreck.local:~/alertreck/alertrack/` |
| Open SSH session | `ssh alertreck@alertreck.local` |

---

## Part 9  Troubleshooting

| Problem | Fix |
|---|---|
| `onnxruntime not found` | Activate venv first: `source ~/alertreck/venv/bin/activate` |
| `No module named sounddevice` | `sudo apt install -y libportaudio2` then `pip install sounddevice` |
| `Permission denied` on SSH | SSH not enabled  create empty `ssh` file on boot partition (see Part 3) |
| `Permission denied` (password rejected) | Wrong **username**  use `alertreck@…`, not `pi@…` (no default `pi` user on Bookworm) |
| Pi not found at `alertreck.local` | Find IP via `ping alertreck.local`, then: `ssh alertreck@192.168.1.88` |
| Model not found error | Re-export on Mac (see Part 5, pass `--model models/custom_cnn/best_model.pt`), then copy to Pi |
| No audio device found | I2S overlay didn't load  check `arecord -l` shows `sndrpigooglevoi`; confirm `dtparam=i2s=on` + `dtoverlay=googlevoicehat-soundcard` in `config.txt`, reboot (Part 6A) |
| Mic captures silence (peak ≈ 0) | Re-check INMP441 wiring  L/R→GND and the SD/WS/SCK pins; a loose SD wire is the usual cause (`../alertrack/deploy/INMP441_SETUP.md`) |
| Real events never trigger | INMP441 floor is low  confirm `SILENCE_THRESHOLD` / `ONSET_MIN_RMS = 0.0015` in `config.py` (Part 6A step 3) |
| `arecord` works but Python is silent | PortAudio opened the wrong device  set `MIC_DEVICE_INDEX = "googlevoicehat"` in `config.py` |

---

## Part 10  Connect the SIM808 GPS / GSM Module

The SIM808 provides **GPS coordinates** (for geotagging alerts) and **GSM SMS** (to notify rangers),
both over a single UART serial link. This part covers GPS; SMS uses the same wiring.

### 1. Wire the SIM808 to the Pi 4 GPIO

| SIM808 pin | Pi 4 pin | Notes |
|---|---|---|
| `VCC` (module power) | **External 5V / ≥2A supply**, *not* the Pi's 5V | SIM808 draws ~2A bursts when the GSM radio transmits  powering it from the Pi will brown-out and reboot the Pi |
| `GND` | Pi GND (pin 6) **and** the external supply GND | Common ground is required |
| `TXD` | Pi `GPIO15 / RXD` (pin 10) | SIM808 TX → Pi RX |
| `RXD` | Pi `GPIO14 / TXD` (pin 8) | SIM808 RX → Pi TX |

Attach the **GPS antenna** (the active patch antenna) and place it with a clear view of the sky 
GPS will not get a fix indoors.

### 2. Enable the Pi's UART

The default `/dev/ttyAMA0` (PL011) on a Pi 4 is used by Bluetooth and the serial login console. Free it:
```bash
sudo raspi-config
#  Interface Options → Serial Port
#    "login shell over serial?"  → NO
#    "serial port hardware enabled?" → YES
```
Then disable Bluetooth so it doesn't claim the good UART, and reboot:
```bash
echo "dtoverlay=disable-bt" | sudo tee -a /boot/firmware/config.txt
sudo systemctl disable hciuart
sudo reboot
```
After reboot the SIM808 is on `/dev/ttyAMA0` at 9600 baud  matching `SIM808_PORT` in `config.py`.

### 3. Verify the serial link and get a GPS fix

Add yourself to the `dialout` group (one-time) so you can open the port without sudo:
```bash
sudo usermod -aG dialout alertreck   # log out / back in afterwards
```
Talk to the module and power on its GPS:
```bash
# 'AT' should echo 'OK'. Then power GPS on and stream NMEA:
python3 -c "
import serial, time
s = serial.Serial('/dev/ttyAMA0', 9600, timeout=2)
for cmd in (b'AT', b'AT+CGNSPWR=1', b'AT+CGNSOUT=1'):
    s.write(cmd + b'\r\n'); time.sleep(0.5)
    print(cmd, '->', s.read(s.in_waiting or 64))
"
```
Each command should return `OK`. Once the antenna has a sky view, a fix takes **30 s – several minutes**
the first time (cold start). Test the project's reader directly:
```bash
cd ~/alertreck
python3 -m alertrack.sensors.gps      # prints coordinates once it has a fix
```

### 4. Enable GPS (and GSM) in config

Edit `alertrack/config.py` on the Pi:
```python
GPS_ENABLED = True            # was False
NOTIFY_GSM  = True            # was False  enables SMS alerts
SIM808_PORT = "/dev/ttyAMA0"  # 9600 baud
RANGER_PHONE_NUMBERS = [
    "+250795607062",          # ranger number(s) in E.164 format
]
```

**Validate the GSM link before relying on it** (run on the Pi). Registration first:
```bash
python3 -c "
import serial, time
s=serial.Serial('/dev/ttyAMA0',9600,timeout=1)
def at(c): s.reset_input_buffer(); s.write((c+'\r\n').encode()); time.sleep(1); print(c,'->',s.read(s.in_waiting or 256).decode(errors='ignore').strip())
at('ATE0'); at('AT+CSQ'); at('AT+CREG?'); at('AT+COPS?')
"
# Want: CSQ first number >=10 ; CREG: 0,1 or 0,5 (registered) ; COPS shows the carrier
```
Then send a real test SMS to the ranger via the project's own sender:
```bash
python3 -c "
from alertrack.alerts.notifier import _sim808_send_sms
print('SMS sent:', _sim808_send_sms('+250795607062','ALERTRECK test - system online','/dev/ttyAMA0',9600,15.0))
"
```
If `AT` returns nothing, swap the TX/RX wires. If SMS reboots the module, the SIM808 power supply
is too weak (add a 1000 µF cap across VBAT, or use a stronger external supply).

Restart and watch the logs for a fix:
```bash
sudo systemctl restart alertrack
journalctl -u alertrack -f
```
When the GPS has a lock, alerts change from `Location: UNKNOWN (GPS unavailable)` to real coordinates,
and an SMS is sent to each ranger number.

> **GPS/SMS share one UART.** The daemon uses the poll-on-demand `SIM808AT` reader (it opens the port
> only to read a fix, then releases it) precisely so SMS and GPS never hold `/dev/ttyAMA0` at the same
> time. Don't switch back to a continuous NMEA reader, or SMS sends will fail with "port busy".

> **Tip:** until the antenna has a clear sky view, set `SIMULATE_GPS = True` in `config.py` to test the
> alert/SMS flow with placeholder coordinates  useful for indoor bench testing.

---

## Quick Reference

```
Pi address     : alertreck.local   (current IP 192.168.1.88  DHCP, may change on reboot)
Pi hostname    : alertreck.local
SSH user       : alertreck
Project path   : /home/alertreck/alertreck/
Model path     : /home/alertreck/alertreck/models/custom_cnn/alertreck_cnn.onnx
Venv path      : /home/alertreck/alertreck/venv/
Service name   : alertrack
Mic            : INMP441 I2S MEMS (ALSA card `sndrpigooglevoi`; default via /etc/asound.conf)
SIM808 (GPS/GSM): /dev/ttyAMA0 @ 9600 baud  (UART; GPS=AT+CGNSPWR/CGNSOUT)
```

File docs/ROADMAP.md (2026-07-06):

# Alertreck — Project Roadmap

**Student:** Orpheus Mhizha Manga · **Program:** ALU BSc SE (Machine Learning), 2026 Capstone
**Supervisor:** Hubert Apana · **Contact:** o.manga@alustudent.com
**Project:** Offline edge-AI acoustic poaching-threat detection for remote African conservation parks
**Full title:** *Offline Edge AI for Anti-Poaching Acoustic Surveillance: Benchmarking Pretrained Embeddings, Metric Learning, Supervised Classification, and Anomaly Detection on Identical Field Hardware*

> **Research questions (from proposal §1.4):**
> - RQ1: Which learning paradigm — supervised classification (CNN), metric learning (ProtoNet), frozen out-of-species transfer (W2V2-L2), or unsupervised anomaly detection (Conv-AE / OC-SVM) — achieves highest AUC-ROC, per-class F1, and lowest FPR on a 7-class African savannah acoustic dataset on identical edge hardware?
> - RQ2: How does per-class detection performance differ across the five models at SNR 5 / 10 / 20 dB, and which sound class poses the greatest detection challenge under field-representative interference?
> - RQ3: Can the SIM808 GSM/GPS module acquire a GPS fix and append device coordinates to a labelled SMS alert within the 30 s end-to-end latency budget on Pi 4 hardware, and what is the typical fix-acquisition time outdoors?
> - RQ4: Do Grad-CAM heatmaps on the winning model's mel-spectrogram inputs highlight acoustically expected time-frequency regions, supporting ranger trust?
> - RQ5: Does the out-of-species embedding advantage (Geldenhuys & Niesler, 2026) — a frozen, truncated wav2vec 2.0 layer-2 embedding approaching supervised performance for elephant calls — extend to non-biological threats (gunshots, chainsaws, vehicles) in a multi-class African savannah dataset, and does it retain that advantage on edge hardware after INT8 quantisation?

---

## 1. Locked design parameters

These are fixed by the approved proposal (May 2026). Deviations require supervisor approval.

### 1.1 Seven-class acoustic threat taxonomy

| Label | Kind | Description |
|---|---|---|
| `background_animals` | background | Non-threat wildlife: birds, elephants, lions, horses, insects, frogs |
| `background_wind_rain` | background | Weather / natural ambience: rain, wind, thunderstorm, sea waves, fire |
| `threat_gunshot` | threat | Firearm discharge (rifle, shotgun) |
| `threat_chainsaw` | threat | Chainsaw running / cutting |
| `threat_vehicle` | threat | Truck / motorbike / ATV engine in park |
| `threat_human` | threat | Human voice, shouting, footsteps, machete |
| `threat_dog` | threat | Barking / howling — poacher-dog indicator |

> **Note:** `normal` class was split into `background_animals` and `background_wind_rain` (2026-04-19) for cleaner source tracking and balanced augmentation control.

### 1.2 Audio specification

| Parameter | Value | Justification |
|---|---|---|
| Sample rate | 44.1 kHz mono | Captures full chainsaw / vehicle harmonic content up to Nyquist 22.05 kHz; the INMP441 captures at 48 kHz and is resampled to 44.1 kHz to match the training pipeline |
| Clip length | 3 s, 50 % overlap | Ensures full gunshot transient captured regardless of onset position |
| Amplitude | RMS-normalised to −23 dBFS (EBU R128) | Removes gain variation across dataset sources |
| Mel features | 128-bin log-mel, 25 ms window, 10 ms hop, Hann | Input for CNN, ProtoNet, Conv-AE |
| wav2vec input | 3 s mono waveform resampled to 16 kHz | Native input for the frozen wav2vec 2.0 layer-2 embedding (W2V2-L2 arm); matches the model's pretraining sample rate |
| MFCC features | 40-coeff + Δ + ΔΔ → 120-dim vector per frame | Input for OC-SVM; RBF kernel tractable at this dimensionality |

### 1.3 Five-model comparative architecture (four paradigms)

| Model | Paradigm | Input | Loss | Key detail |
|---|---|---|---|---|
| **CNN** | Supervised | 128-bin log-mel + SpecAugment | Focal loss γ=2 + tempered (sqrt) class weights | 4 conv blocks + FC; ~1.2 M params; encoder reused by ProtoNet |
| **ProtoNet (CNN enc)** | Metric learning | 128-bin log-mel + SpecAugment | Prototypical loss + SupCon (λ=0.1) | N=7, K=5 support, Q=15 query per episode; SupCon pulls same-class embeddings across episodes; t-SNE visualisation |
| **W2V2-L2 + linear head** | Frozen transfer (out-of-species) | 16 kHz raw waveform → frozen wav2vec 2.0 layer-2 embedding (768-dim mean-pooled) | Cross-entropy + focal weighting | wav2vec 2.0 base truncated at layer 2 (~10 % of params); encoder frozen, only a 768→7 linear head trained; no fine-tuning (Geldenhuys & Niesler, 2026) |
| **Conv-AE** | Unsupervised anomaly | 128-bin log-mel + compound aug | MSE reconstruction | 3-layer encoder → 16×16×128 latent; symmetric decoder |
| **OC-SVM** | Unsupervised (classical baseline) | 120-dim MFCC+Δ+ΔΔ + compound aug | One-class hinge | RBF kernel; ν=0.1; grid search for γ; provides the interpretability / compute floor |

> **Note:** tiny-AST (a supervised, fine-tuned audio transformer) was dropped on 2026-06-01 and replaced by **W2V2-L2**. Fine-tuning a transformer on a small corpus overfits under domain shift; a frozen, truncated wav2vec 2.0 layer-2 embedding introduces a genuinely distinct fourth paradigm (frozen out-of-species transfer) rather than a second supervised architecture, and is the empirical vehicle for RQ5 (Geldenhuys & Niesler, 2026).

### 1.4 Dataset split

- **60 / 20 / 20** train / val / test, **group-aware** (assigned by parent recording, stratified by class), fixed seed `42` — segments of one recording never span splits, preventing leakage (`scripts/grouping.py`)
- Test set is locked before any augmentation is applied to training folds
- Validation and test sets receive **only base preprocessing** (steps 1–5), not augmentation steps 6a–6e

### 1.5 Hardware target

| Component | Spec | Role | Status |
|---|---|---|---|
| Raspberry Pi 4 Model B | 2 GB RAM, quad-core ARM Cortex-A72 @ 1.8 GHz | Edge processing, inference, alert transmission, local event logging | ● in hand · hostname `alertreck.local` (192.168.1.88) |
| INMP441 I2S MEMS microphone | Digital I2S (no analog hum), 60 Hz–15 kHz; L/R→GND left channel | Continuous outdoor capture at 48 kHz, resampled to 44.1 kHz mono | ● deployed · replaced the USB mic, eliminating the mains-hum problem |
| SIM808 GSM/GPRS/GPS module | Quad-band 850/900/1800/1900 MHz, UART serial, built-in GPS receiver | SMS alert delivery (MTN/Airtel Rwanda, no data plan) + device GPS coordinates | ● in hand |
| 32 GB Class 10 MicroSD card | Class 10, read ≥ 45 MB/s | OS, model weights, SQLite event database, evidence audio | ● in hand · Pi OS installed |
| Rwanda SIM card (MTN or Airtel) | Prepaid, GSM only (no data plan required) | Cellular network access for SMS delivery | ● in hand |

**Operational budgets:** ≤ USD 80 BOM · ≤ 5 W continuous · < 30 s end-to-end latency · ONNX · model < 10 MB

### 1.6 Experimental controls (ensures fair comparison across all 5 models)

- Identical preprocessed dataset at 44.1 kHz with 3 s windows (50 % overlap for continuous classes; event-centred for impulsive classes)
- Identical 60/20/20 group-aware split (by parent recording, class-stratified), fixed seed 42
- Identical evaluation hardware (Raspberry Pi 4 Model B, 2 GB RAM)
- Identical nine evaluation techniques applied to all five models across all four paradigms
- Identical SNR injection conditions (5, 10, and 20 dB) for anomaly injection tests
- Experiment tracking: local **MLflow** (offline-first — consistent with no-cloud design constraint)

---

## 2. Dataset sources and provenance

### 2.1 Corpus status (topped up 2026-06-24)

**Total on disk: 11,333 raw clips · Stage 1 complete ●**

| Class | Folder | Target | Current | Status | Sources |
|---|---|---|---|---|---|
| `background_animals` | `dataset/background_animals/` | ≥ 600 | 2,139 | **met ✓** | ESC-50 + DATASET02 animals & birds + ff1010bird |
| `background_wind_rain` | `dataset/background_wind_rain/` | ≥ 600 | 2,000 | **met ✓** | ESC-50 + DATASET02 rainfall & wind + AudioSet |
| `threat_gunshot` | `dataset/threat_gunshot/` | ≥ 300 | 3,304 | **met ✓** | AudioSet extraction |
| `threat_chainsaw` | `dataset/threat_chainsaw/` | ≥ 500 | 568 | **met ✓** | ESC-50 + AudioSet (complete) |
| `threat_vehicle` | `dataset/threat_vehicle/` | ≥ 200 | 1,040 | **met ✓** | ESC-50 + UrbanSound8K |
| `threat_human` | `dataset/threat_human/` | ≥ 200 | 1,242 | **met ✓** | Common Voice + ESC-50 |
| `threat_dog` | `dataset/threat_dog/` | ≥ 200 | 1,040 | **met ✓** | UrbanSound8K + ESC-50 |

All class targets met. Dataset is locked for training.

### 2.2 Dataset sources — detail

#### AudioSet (Google, CC BY 4.0)
CSV metadata vendored under [META_DATA_CSV/](META_DATA_CSV/). Audio queried via YouTube segments using `yt-dlp`.
> Gemmeke et al. (2017). *Audio Set: An ontology and human-labeled dataset for audio events.* IEEE ICASSP.

Scripts: [scripts/audio_extraction/](scripts/audio_extraction/) — `download_chainsaws_500.py`, `download_human_sounds.py`, `download_animal_sounds.py`, `download_env_noise.py`

#### ESC-50 (CC BY-NC 3.0)
880 clips across all 7 classes. 5 s clips at 44.1 kHz mono.
> Piczak (2015). *ESC: Dataset for Environmental Sound Classification.* ACM Multimedia 2015.

Script: [scripts/audio_extraction/extract_esc50.py](scripts/audio_extraction/extract_esc50.py)

#### Freefield1010 / ff1010bird (Mixed CC)
500 randomly sampled bird-positive clips (seed 42) → `background_animals`.
> Stowell & Plumbley (2013). *Detection of Bird Species in Audio.* British Library Audio Collection.

Script: [scripts/audio_extraction/extract_ff1010_birds.py](scripts/audio_extraction/extract_ff1010_birds.py)

#### DATASET02 (local, academic use)
1,800 clips covering elephant, lion, horse, birds, rainfall, wind.
Script: [scripts/audio_extraction/extract_dataset02.py](scripts/audio_extraction/extract_dataset02.py)

#### Mozilla Common Voice (CC0)
~500 English speech clips → `threat_human`.
> Ardila et al. (2020). *Common Voice.* LREC 2020.

#### UrbanSound8K (CC BY-NC)
2,000 clips: `dog_bark` → `threat_dog`; `engine_idling` → `threat_vehicle`.
> Salamon et al. (2014). *A Dataset and Taxonomy for Urban Sound Research.* ACM Multimedia 2014.

Merged via [scripts/audio_extraction/merge_extracted_audio.py](scripts/audio_extraction/merge_extracted_audio.py).

### 2.3 Extraction scripts

| Script | Source | Classes fed |
|---|---|---|
| [scripts/audio_extraction/extract_esc50.py](scripts/audio_extraction/extract_esc50.py) | ESC-50 | threat_chainsaw, threat_vehicle, threat_dog, threat_human, background_animals, background_wind_rain |
| [scripts/audio_extraction/extract_dataset02.py](scripts/audio_extraction/extract_dataset02.py) | DATASET02 | background_animals, background_wind_rain |
| [scripts/audio_extraction/extract_ff1010_birds.py](scripts/audio_extraction/extract_ff1010_birds.py) | ff1010bird | background_animals |
| [scripts/audio_extraction/download_chainsaws_500.py](scripts/audio_extraction/download_chainsaws_500.py) | AudioSet | threat_chainsaw |
| [scripts/audio_extraction/merge_extracted_audio.py](scripts/audio_extraction/merge_extracted_audio.py) | Common Voice + UrbanSound8K | threat_human, threat_dog, threat_vehicle |
| [scripts/data_manifest.py](scripts/data_manifest.py) | all | generates manifest.csv |

---

## 3. Compound augmentation and curriculum training pipeline

> **Source:** Proposal §2.3.7, §3.3, §3.3.1 — directly informed by Mega-ASR (Xie et al., 2026), SpecAugment++ (Wang et al., 2021), FilterAugment (Nam et al., 2022), and Morocutti et al. (2023).

This is the most critical section for model robustness. All prior conservation acoustic classifiers train on atomic single-condition data and fail on the compound degradation profiles of real African field deployment. This pipeline closes that gap.

### 3.1 Full preprocessing pipeline (all 7 steps)

Applied to **all clips** in order. Steps 6a–6e apply to **training folds only**.

| Step | Operation | Parameters | Justification |
|---|---|---|---|
| 1 | **Resample** | Kaiser-best resampling → 44.1 kHz mono | Full chainsaw/vehicle harmonic content up to 22.05 kHz; matches the 44.1 kHz training pipeline (the INMP441 captures at 48 kHz and is resampled on device) |
| 2 | **Normalise** | RMS amplitude → −23 dBFS (EBU R128) | Removes gain variation across sources; prevents loudness shortcuts |
| 3 | **Segment** | Class-dependent 3 s windows: continuous classes use a sliding window (1.5 s step, 50 % overlap); impulsive classes (gunshot, dog) use **event-based selection** — windows centred on energy onsets ≥ 8 dB above the clip's own floor | Captures the transient regardless of onset position; for impulsive classes, drops silent windows that blind slicing would mislabel as a threat (reduces false positives) |
| 4a | **Log-mel spectrogram** | STFT → 128-bin mel filterbank → log; 25 ms window, 10 ms hop, Hann | Input for CNN, ProtoNet, Conv-AE |
| 4b | **Raw waveform (16 kHz)** | 3 s mono waveform resampled 44.1 → 16 kHz | Native input for the frozen wav2vec 2.0 layer-2 encoder (W2V2-L2 arm); matches wav2vec 2.0 pretraining sample rate (Geldenhuys & Niesler, 2026) |
| 4c | **MFCC+Δ+ΔΔ** | DCT → delta → delta-delta; 40 coefficients → 120-dim vector per frame | Input for OC-SVM; RBF kernel tractable at this dimensionality |
| 5 | **Device impulse-response (DIR) calibration** | Sweep-tone impulse response recorded via the deployment microphone; convolved with all training clips | Closes device domain gap between downloaded training data and deployment microphone frequency response (Morocutti et al., 2023) |
| 6a | **SpecAugment** | Time masking: 2 masks, max 40 frames; frequency masking: 2 masks, max 20 bins | Forces model to learn full spectral shape of threats, not just onset timing (Wang et al., 2021) |
| 6b | **Compound augmentation** | Randomly sample 2–4 effects from pool below; physical plausibility filter applied | Simulates real compound field conditions per Mega-ASR (Xie et al., 2026) |
| 6c | **FilterAugment** | Random frequency response curve per clip; magnitude: ±6 dB across random sub-band | Simulates deployment-microphone frequency-response variation across outdoor temperature/humidity (Nam et al., 2022) |
| 6d | **Mixup** | Beta distribution β(0.4); inter-class and intra-class pairs | Additional regularisation; improves class boundary generalisation (Zhang et al., 2018) |
| 6e | **Learnability filter** | Discard augmented clips where Conv-AE reconstruction error exceeds 95th percentile of background distribution | Removes unlearnable hard-negative samples that destabilise training (Mega-ASR WER > 70 % filter principle) |
| 7 | **Split** | Group-aware 60/20/20 (by parent recording, class-stratified); seed 42; test set locked before augmentation applied to training folds | Held-out test set reflects clean baseline; group-aware assignment prevents recording leakage across splits |

### 3.2 Compound augmentation effect pool (step 6b)

Between **2 and 4 effects** are drawn simultaneously per clip. Physical plausibility filter: RIR convolution is **not** combined with dry clipping (acoustically contradictory).

| Effect | Parameters | What it simulates |
|---|---|---|
| Gaussian noise | 5–20 dB SNR | Background ambient noise at varying distances |
| RIR convolution | Recorded room impulse responses | Reverberation in dense vegetation, enclosed spaces |
| Low-pass filter | 2–8 kHz cutoff | Distance attenuation — high frequencies attenuate first |
| MP3 compression | VBR quality 2–7 | Recording device codec degradation |
| Gain perturbation | ±6 dB | Microphone gain variation, wind gust masking |
| Clipping distortion | ≤ 10th percentile amplitude threshold | Electronic overload / cheap hardware saturation |

### 3.3 Curriculum training schedule (three phases)

Following Mega-ASR's progressive difficulty strategy (Xie et al., 2026). Models trained on uniform mixtures of all difficulty levels simultaneously collapse on severe compound inputs — the curriculum prevents this.

| Phase | Training weeks | Augmentation applied | SNR range | Rationale |
|---|---|---|---|---|
| **Phase A** | W3–W4 | Clean + mild single-condition only (steps 6a, 6d) | ≥ 15 dB | Builds reliable acoustic feature extraction on clean spectral structure; stable encoder representations |
| **Phase B** | W5 | Medium compound: 2–3 effects at moderate severity (steps 6a–6d, severity k ≤ 0.5) | 10–15 dB | Introduces realistic field degradation; prevents overfitting to clean training distribution |
| **Phase C** | W6 | Full compound pipeline: 2–4 effects at full severity including far-field and device distortion (steps 6a–6e) | 5–10 dB | Exposes models to hardest compound conditions; learnability filter (step 6e) applied to prevent collapse on unrecoverable samples |

**Applies to:** CNN, W2V2-L2, ProtoNet training pipelines (identical schedule). For W2V2-L2 the wav2vec 2.0 layer-2 encoder is held **fixed in all phases** — only the lightweight linear head receives gradient updates across the curriculum (Geldenhuys & Niesler, 2026).

**For Conv-AE and OC-SVM** (trained on background-class audio only):
- Phase A: clean background clips only
- Phase B: medium compound-degraded background clips
- Phase C: full compound augmentation on background audio

This ensures the anomaly detectors build a robust model of what normal background sounds like under compound field conditions, not just under clean recording conditions — the primary cause of elevated false-positive rates in field-deployed anomaly detectors.

### 3.4 ProtoNet-specific: SupCon loss term

For the ProtoNet metric learning arm, a supervised contrastive loss (SupCon) is added alongside the standard prototypical loss:

- **Loss:** `L = L_proto + 0.1 × L_SupCon`
- **Effect:** Pulls all embeddings of the same class together across episodes (not just within one episode), improving robustness to intra-class acoustic variation
- **Especially relevant for:** `threat_human` and `threat_vehicle` classes, which exhibit high intra-class spectral diversity

Reference: Gazneli et al. (2022).

---

## 4. Nine-technique evaluation framework

> **Source:** Proposal §3.5.2 — applied identically to all five models.

| # | Technique | Target | What it measures |
|---|---|---|---|
| 1 | **AUC-ROC curve** | > 0.85 (all five models) | Primary headline metric; detection performance independent of threshold |
| 2 | **Per-class F1 score** | > 0.80 (all 7 classes, supervised + metric models) | Balance between alert sensitivity and FPR per threat category |
| 3 | **Threshold ablation** | — | Sweeps detection threshold across full range; identifies optimal operating point for field conditions |
| 4 | **False-positive rate test** | < 20 % | Evaluates on held-out normal audio (rain, wind, insects) not seen during training |
| 5 | **Anomaly injection test** | — | Recall evaluation: mixes labelled gunshot, human voice, vehicle into normal audio at SNR 5 / 10 / 20 dB |
| 6 | **Latency benchmark (Pi 4)** | < 30 s end-to-end | Measures inference time from audio onset to SMS delivery on deployment hardware |
| 7 | **Energy benchmark** | ≤ 5 W continuous | Measures continuous power draw on Pi 4 during active monitoring |
| 8 | **GPS fix quality** | Valid fix ≤ 60 s cold start; coordinates within 5 m CEP | Validates SIM808 GPS time-to-first-fix and coordinate accuracy under open-sky and light-canopy conditions |
| 9 | **Grad-CAM validation** | Qualitative | Confirms highlighted spectrogram regions match acoustically expected features of each class |

---

## 5. Implementation stages — design to deployment

Ten stages across eight proposal phases. Each stage maps to a proposal section and produces a concrete artefact.

---

### Stage 0 — Design lock-in ● done

**Goal:** Freeze all design parameters in version-controlled docs.
**Proposal ref:** §1.3–§1.5
**Outputs:** `ROADMAP.md` · `DESIGN.md` · `PROPOSAL.md`
**Status:** ● complete

---

### Stage 1 — Data engineering ● done

**Goal:** Assemble, organise, and document 11,333 raw audio clips across all 7 classes (8,907 at Stage-1 close 2026-05-27; topped up to 11,333 on 2026-06-24).
**Proposal ref:** §3.3 (Table 2)
**Tasks:**
1. ● `threat_chainsaw` at 568 clips — above 500 target (completed 2026-05-27)
2. ● Data manifest generated — 11,333 files across 7 classes
3. ● Classes mapped to 7-class taxonomy
4. ● ff1010bird merged into `background_animals/` with `ff1010bird__` prefix

**Artefact:** `dataset/` directory with 11,333 labelled clips across 7 class folders
**Status:** ● complete

---

### Stage 2 — Deterministic preprocessing pipeline ● done

**Goal:** One deterministic `AudioPreprocessor` implementing all 7 pipeline steps from §3.1 above.
**Proposal ref:** §3.3 (Table 3), §2.3.7
**Implementation:** Python 3.10 · librosa 0.10+ · numpy (no scipy, no audiomentations — all effects from scratch)

**Tasks:**
1. ● Rewrote [scripts/audio_preprocessing.py](scripts/audio_preprocessing.py) — full 7-step pipeline:
   - Step 1: Kaiser-best resample → 44.1 kHz mono
   - Step 2: RMS normalise → −23 dBFS (EBU R128)
   - Step 3: Class-dependent 3 s windows (132,300 samples) — sliding 1.5 s step for continuous classes; event-centred selection for impulsive classes (gunshot, dog)
   - Step 4a: 128-bin log-mel (STFT win=1102/25 ms, hop=441/10 ms, Hann, n_fft=2048) → (128, 300) shape
   - Step 4b: 16 kHz raw-waveform branch for the W2V2-L2 frozen encoder — **new requirement from the updated proposal (2026-06-01); not yet emitted, pipeline extension + re-run pending**
   - Step 4c: MFCC+Δ+ΔΔ (40 coefficients → 120-dim per frame)
   - Step 5: DIR calibration stub (active with `--dir-ir usb_mic_ir.wav`)
   - Steps 6a–6e: SpecAugment, compound aug pool, FilterAugment, mixup utility, learnability filter stub
   - Step 7: 60/20/20 group-aware split (by parent recording, class-stratified), seed 42; test set locked
2. ◐ Device-IR (DIR) calibration (Step 5) — optional; the INMP441 I2S mic is deployed and the USB mains-hum problem that delayed this is resolved, so a `--dir-ir` re-run with the new mic remains a future refinement, not a blocker
3. ● All augmentation steps 6a–6d implemented from scratch (numpy + librosa + ffmpeg); 6e stub until Conv-AE trained
4. ● `.npz` shards written to `data/processed/{mel,mfcc}/{train,val,test,train_aug_A,train_aug_B,train_aug_C}/`
5. ● `data/processed/manifest.json` and `splits.json` written

**Preprocessed output (group-aware re-shard 2026-06-24):**

| Split | Files | Windows |
|---|---|---|
| `mel/train` (clean) | 6,799 | 14,854 |
| `mel/train_aug_A` (Phase A ×1) | 6,799 | 14,854 |
| `mel/train_aug_B` (Phase B ×2) | 6,799 | 29,708 |
| `mel/train_aug_C` (Phase C ×3) | 6,799 | 44,562 |
| `mel/val` | 2,268 | 5,844 |
| `mel/test` | 2,266 | 5,925 |
| `mfcc/{same splits}` | — | same counts |

**Artefact:** [scripts/audio_preprocessing.py](scripts/audio_preprocessing.py) · `data/processed/` shards · `manifest.json` · `splits.json`
**Status:** ◐ mel/mfcc shards complete; **16 kHz raw-waveform branch (step 4b) for W2V2-L2 still to be added and the pipeline re-run** (new requirement, updated proposal). DIR calibration also pending hardware fix — neither blocks CNN/ProtoNet training.

---

### Stage 3 — Supervised + metric model training (CNN · ProtoNet) ◐

**Goal:** Train and checkpoint the two CNN-encoder models (supervised + metric paradigms) under the three-phase curriculum.
**Proposal ref:** §3.5.1 (Table 4), §3.3.1
**Proposal weeks:** W3–W5
**Notebooks:** `notebooks/03a-train-cnn.ipynb` · `notebooks/03b-train-protonet.ipynb`
**Experiment tracking:** local MLflow (offline)

#### 3a. CNN (supervised, focal loss γ=2) ◐ notebook ready — awaiting Kaggle GPU run
- Input: 128-bin log-mel (128 × 300) + SpecAugment
- Architecture: 4 conv blocks + AdaptiveAvgPool + FC head; ~1.2 M parameters
- Encoder exposes `encode()` method returning 256-dim embedding — reused by ProtoNet (Stage 3b)
- Curriculum: Phase A (epochs 1–15, clean + aug_A) → Phase B (epochs 16–25, clean + aug_B) → Phase C (epochs 26+, clean + aug_C)
- Notebook updated 2026-05-27: paths, shape (259→300), curriculum DataLoader switching, SpecAugment spec-correct, ONNX export cell added

#### 3b. ProtoNet (metric learning, prototypical loss + SupCon λ=0.1)
- Input: 128-bin log-mel + SpecAugment
- Episode config: N=7 classes, K=5 support shots, Q=15 query shots per episode
- Encoder: reuse CNN encoder from Stage 3a (shared weights — train CNN first)
- Loss: `L = L_proto + 0.1 × L_SupCon`
- Curriculum: same three-phase schedule
- Visualisation: t-SNE of 7-class embedding space after each curriculum phase

**Outputs:** `models/cnn/` · `models/protonet/` — each with weights + MLflow metrics + training curves

---

### Stage 4 — Frozen-transfer + unsupervised detector training (W2V2-L2 · Conv-AE · OC-SVM) ○

**Goal:** Train the frozen out-of-species transfer arm plus both unsupervised detectors, under the curriculum (Conv-AE / OC-SVM on background-class audio only).
**Proposal ref:** §3.5.1 (Table 4), §3.3.1
**Proposal weeks:** W5–W6
**Notebooks:** `notebooks/04a-train-w2v2-l2.ipynb` · `notebooks/04b-train-conv-ae.ipynb` · `notebooks/04c-train-oc-svm.ipynb`

#### 4a. W2V2-L2 (frozen out-of-species transfer, cross-entropy + focal weighting) — **new arm, replaces tiny-AST**
- Input: 3 s mono waveform resampled to 16 kHz → frozen wav2vec 2.0 base, **truncated at layer 2** → 768-dim mean-pooled embedding
- Encoder **frozen in every phase** (~10 % of full wav2vec params retained); only a 768→7 linear head is trained — no fine-tuning of the embedding (Geldenhuys & Niesler, 2026)
- Frameworks: HuggingFace `transformers` + `torchaudio` for embedding extraction; linear head in PyTorch (scikit-learn `LogisticRegression` fallback)
- Curriculum: same three-phase schedule; only the linear head receives gradient updates
- Directly answers RQ5 — does the out-of-species advantage extend to non-biological threats and survive INT8 quantisation?
- Depends on Stage 2 emitting the 16 kHz raw-waveform shards (step 4b); independent of the CNN, so can train in parallel with Stage 3

#### 4b. Conv-AE (MSE reconstruction)
- Input: 128-bin log-mel + compound augmentation
- Architecture: 3-layer encoder → 16×16×128 latent; symmetric decoder
- Training data: `background_animals` + `background_wind_rain` only
- Curriculum:
  - Phase A (W3–W4): clean background clips only
  - Phase B (W5): medium compound-degraded background clips
  - Phase C (W6): full compound augmentation on background (learnability filter applied)
- Anomaly threshold: 95th percentile reconstruction error on held-out background val set

#### 4c. OC-SVM (one-class hinge, classical baseline)
- Input: 120-dim MFCC+Δ+ΔΔ + compound augmentation
- Kernel: RBF; ν=0.1 contamination; γ selected via grid search
- Training data: background classes only, same curriculum phasing
- Note: OC-SVM does not benefit from deep curriculum in the same way — apply augmented features from Phase C directly

**Outputs:** `models/w2v2_l2/` · `models/conv_ae/` · `models/oc_svm/` with weights, embeddings/linear head, reconstruction thresholds, decision boundaries

---

### Stage 5 — Comparative evaluation (nine-technique framework) ○

**Goal:** The headline study answering RQ1 and RQ2. Select the winning model for deployment.
**Proposal ref:** §3.5.2, §1.3.1 Objective 3
**Proposal week:** W7
**Notebook:** `notebooks/05_comparative_eval.ipynb`

**Tasks:**
1. Run all nine evaluation techniques (§4 above) on all five models using the locked test set
2. Compile four-paradigm results table: supervised (CNN) vs metric (ProtoNet) vs frozen transfer (W2V2-L2) vs unsupervised anomaly (Conv-AE / OC-SVM)
3. Run anomaly injection tests at SNR 5 / 10 / 20 dB for all models
4. Run threshold ablation sweeps; identify optimal operating threshold per model
5. Benchmark inference latency on Raspberry Pi 4 (not laptop) for all five models
6. Measure energy draw on Pi 4 during inference
7. Select winning model: highest AUC-ROC + F1 + lowest FPR + meets latency / size constraints

**Outputs:**
- `reports/comparative_eval.md` — four-paradigm results table
- `reports/figures/` — AUC-ROC curves, confusion matrices, t-SNE embedding plots
- `reports/winning_model.md` — selection rationale

---

### Stage 6 — Edge deployment (ONNX · Pi 4 integration) ○

**Goal:** Export winning model to ONNX and integrate into the `alertrack/` runtime daemon.
**Proposal ref:** §3.5.1, §3.4
**Proposal week:** W8

**Tasks:**
1. Export winning model → ONNX (opset 17) via `scripts/export_model.py`
2. Verify: model size < 10 MB; accuracy degradation < 2 % from float32 baseline
3. Integrate ONNX model into [alertrack/inference/model.py](alertrack/inference/model.py)
4. Wire [alertrack/audio/recorder.py](alertrack/audio/recorder.py) → [alertrack/audio/preprocess.py](alertrack/audio/preprocess.py) → `ModelInference`
5. Benchmark on Pi 4: end-to-end inference latency (audio capture → class label) — target < 25 s (leaving 5 s margin for SMS transmission)
6. Benchmark continuous power draw — target ≤ 5 W
7. Validate systemd service auto-restart on [alertrack/alertrack.service](alertrack/alertrack.service)

**Artefact:** Deployed ONNX model in `models/` · updated `alertrack/` runtime · latency + energy benchmark report

---

### Stage 7 — SIM808 GPS + GSM SMS integration ○

**Goal:** Add GPS coordinate tagging and SMS alert delivery via SIM808. Answers RQ3.
**Proposal ref:** §2.3.5, §3.4, §3.5.2 (technique 8)
**Proposal weeks:** W8–W9

#### 7a. SIM808 GPS coordinate acquisition
- SIM808 built-in GPS outputs NMEA sentences via UART serial at 9600 baud
- Enable GPS: `AT+CGNSPWR=1`, then `AT+CGNSOUT=1` to stream NMEA on the serial port
- Existing NMEA parser in [alertrack/sensors/gps.py](alertrack/sensors/gps.py) handles `$GPGGA` / `$GPRMC` directly — no code change required
- Alternative: poll `AT+CGNSINF` for structured single-line response (lat, lon, alt, speed, fix status)
- Require ≥ 3 satellites for a valid fix before any alert is dispatched; fall back to last known coordinates if fix lost
- Validate fix quality: log satellite count and fix status in SQLite `SystemStatus`
- Target: valid fix within 60 s cold start; coordinate accuracy within 5 m CEP (SIM808 spec)

#### 7b. SIM808 GSM SMS alert delivery
- Implement full AT command sequence in [alertrack/alerts/notifier.py](alertrack/alerts/notifier.py)
- Commands: `AT+CMGF=1` (text mode) → `AT+CMGS="<number>"` → message → `chr(26)` (send)
- SMS payload format: `ALERTRECK | <class> | Conf: x% | GPS: lat,lon | HH:MM`
- Network: MTN or Airtel Rwanda GSM (quad-band); no data plan required — SMS only
- Retry logic: up to 3 attempts with 5 s backoff; log each attempt and outcome to SQLite `AlertLog`
- Test end-to-end: loudspeaker playback → INMP441 mic → inference → SMS delivered → measure 95th-percentile latency across 100 trials; target < 30 s

#### 7c. SQLite event database
- Implement in [alertrack/storage/logger.py](alertrack/storage/logger.py) and [alertrack/storage/evidence.py](alertrack/storage/evidence.py)
- Schema: `DetectedEvent` · `AudioSegment` · `AlertLog` · `SystemStatus`
- Log every detected event regardless of alert threshold (for audit and false-positive analysis)

**Artefact:** SIM808 GPS/SMS pipeline · SQLite event log · GPS fix validation report

---

### Stage 8 — Grad-CAM explainability + Flask LAN dashboard + final evaluation ○

**Goal:** Add explainability layer, build LAN dashboard, and complete the full nine-technique evaluation. Answers RQ4.
**Proposal ref:** §1.3.1 Objective 3, §3.5.2 (technique 9), §3.4
**Proposal weeks:** W9–W10

#### 8a. Grad-CAM (winning model only)
- Library: `pytorch-grad-cam` or `tf-explain` depending on winning model framework
- Apply to mel-spectrogram inputs of the winning model
- Generate heatmaps for each of the 7 threat classes using representative test clips
- Qualitative validation: do highlighted regions match expected acoustic features?
  - `threat_gunshot`: sharp transient in low-to-mid frequency range
  - `threat_chainsaw`: harmonic stack at 50–200 Hz + overtones
  - `threat_vehicle`: low-frequency engine harmonics
  - `threat_human`: voiced speech formants (300–3000 Hz)
  - `threat_dog`: bark envelope with formant structure

#### 8b. Flask LAN dashboard
- Implement in `alertrack/` or separate `dashboard/` module
- Served at port 5000 on Pi 4 local network interface (no external internet access)
- Pages: real-time anomaly score stream · class label + confidence · GPS coordinates (lat/lon from SIM808) · Grad-CAM spectrogram overlay · alert history from SQLite · system health (CPU temp, uptime, GSM signal dB)

#### 8c. Full nine-technique evaluation (system-level)
- Re-run techniques 6–8 (latency, energy, GPS fix quality) on the complete integrated system (not models in isolation)
- 100-trial latency test: loudspeaker playback → SMS delivered → measure 95th percentile
- Produce final `reports/system_eval.md`

**Artefact:** Grad-CAM heatmap gallery · Flask dashboard code · `reports/system_eval.md`

---

### Stage 9 — Final report + submission package ○

**Goal:** Reproduce all results from scratch in ≤ 1 command; produce final thesis.
**Proposal ref:** §1.8 (W10+)
**Proposal week:** W10

**Tasks:**
1. Write `Makefile` or `scripts/reproduce.sh`: one command runs full pipeline (download → preprocess → train 5 models under curriculum → evaluate → export → deploy)
2. Finalize data card, model card, and experiment registry in MLflow
3. Confirm all result tables in thesis match outputs of `make reproduce`
4. Thesis chapters follow proposal section numbering:
   - Chapter 1: Introduction (maps to §1)
   - Chapter 2: Literature Review (maps to §2)
   - Chapter 3: Methodology (maps to §3)
   - Chapter 4: Results & Discussion (comparative eval tables + Grad-CAM analysis)
   - Chapter 5: Conclusion + future work

**Artefact:** `make reproduce` command · final thesis PDF · submission package

---

## 6. Ten-week Gantt (aligned to proposal Table 11)

| Phase | W1 | W2 | W3 | W4 | W5 | W6 | W7 | W8 | W9 | W10 |
|---|---|---|---|---|---|---|---|---|---|---|
| **Phase 1:** Data & Preprocessing (Stages 1–2) | █ | █ | | | | | | | | |
| **Phase 2:** Supervised & Metric Models — CNN, ProtoNet (Stage 3) | | | █ | █ | █ | | | | | |
| **Phase 3:** Frozen Transfer & Unsupervised Detectors — W2V2-L2, Conv-AE, OC-SVM (Stage 4) | | | | | █ | █ | | | | |
| **Phase 4:** Comparative Evaluation (Stage 5) | | | | | | | █ | | | |
| **Phase 5:** Edge Deployment (Stage 6) | | | | | | | | █ | | |
| **Phase 6:** Direction + GSM Integration (Stage 7) | | | | | | | | █ | █ | |
| **Phase 7:** Grad-CAM, Dashboard & Evaluation (Stage 8) | | | | | | | | | █ | █ |
| **Phase 8:** Writing & Submission (Stage 9) | | | | | | | | | | █ |

> **Current date: 2026-06-01.** Stage 1 is complete; Stage 2 needs the new 16 kHz waveform branch (step 4b) for W2V2-L2. Stage 3a (CNN) notebook is ready and uploading to Kaggle for GPU training. The model line-up was updated 2026-06-01 (tiny-AST → W2V2-L2). All hardware is in hand and the Pi is accessible at `alertreck.local`.

---

## 7. Status snapshot (2026-06-01)

| Stage | Name | Status | Next action |
|---|---|---|---|
| 0 | Design lock-in | ● done | — |
| 1 | Data engineering | ● done | — |
| 2 | Preprocessing pipeline | ● done | 16 kHz raw-waveform branch (step 4b) feeds W2V2-L2; optional `--dir-ir` re-run with the INMP441 is a future refinement |
| 3a | CNN training | ◐ | Upload shards to Kaggle, run `03a-train-cnn.ipynb` on GPU |
| 3b | ProtoNet training | ○ | After CNN encoder weights available (Stage 3a) |
| 4a | W2V2-L2 frozen transfer | ○ | New arm (replaces tiny-AST); needs 16 kHz waveform shards — extract frozen layer-2 embeddings, train linear head |
| 4b | Conv-AE training | ○ | Unlocks learnability filter (step 6e) in preprocessing |
| 4c | OC-SVM training | ○ | After Conv-AE threshold established |
| 5 | Comparative evaluation | ○ | All nine techniques on all five models across four paradigms |
| 6 | Edge deployment | ◐ skeleton | Export winning model to ONNX; plug into `alertrack/` daemon |
| 7 | SIM808 GPS + GSM | ◐ skeleton | Hardware in hand; wire NMEA reader + AT command SMS; add ranger numbers to `config.py` |
| 8 | Grad-CAM + dashboard | ○ | After winning model selected in Stage 5 |
| 9 | Final report + submission | ○ | `make reproduce` + thesis writing |

Legend: ○ not started · ◐ partial / skeleton exists · ● done

---

## 8. Decisions logged

| Date | Decision | Reason |
|---|---|---|
| 2026-04-15 | `threat_dog` added as 6th/7th threat class | Poacher-dog indicator added per proposal amendment |
| 2026-04-19 | `normal` split → `background_animals` + `background_wind_rain` | Cleaner source tracking; balanced augmentation control |
| 2026-04-19 | Old YAMNet notebook deleted | Replaced by five-model comparative architecture |
| 2026-04-19 | MLflow chosen for experiment tracking | Offline-first — no cloud dependency |
| 2026-05-24 | ProtoNet added as third model paradigm | Proposal finalised; metric learning is the primary novel contribution |
| 2026-05-25 | USB microphone + SIM808 replaces ReSpeaker 4-Mic Array + SIM800L | SIM808 built-in GPS provides device coordinates for alert tagging; simpler hardware stack, lower cost, no multi-channel sync required |
| 2026-05-24 | Compound augmentation + curriculum training added | §2.3.7 from Mega-ASR (Xie et al., 2026); prevents collapse on field-deployment compound degradation conditions |
| 2026-05-27 | Stage 1 complete — 8,907 clips, all 7 class targets met | `threat_chainsaw` reached 567 (target 500); dataset locked for training |
| 2026-05-27 | Stage 2 complete — preprocessing pipeline runs end-to-end | All shards generated: 7,359 clean train windows + 44,154 curriculum aug windows; DIR calibration deferred pending USB mic hum fix |
| 2026-05-27 | All hardware in hand and deployed | Pi at alertreck.local (192.168.1.88); USB mic, SIM808, 32 GB SD, Rwanda SIM all confirmed |
| 2026-05-27 | CNN notebook updated for new data | Shape 259→300, curriculum DataLoader, SpecAugment corrected, ONNX export added; ready for Kaggle GPU run |
| 2026-06-01 | **tiny-AST dropped; replaced by W2V2-L2** (frozen wav2vec 2.0 layer-2 + linear head) | Updated proposal §2.3.4, §3.5.1: fine-tuning a transformer on a small corpus overfits under domain shift. A frozen, truncated layer-2 embedding is a genuinely distinct 4th paradigm (frozen out-of-species transfer) and the empirical vehicle for the new RQ5 (Geldenhuys & Niesler, 2026). `notebooks/03b-train-tiny-ast.ipynb` and `models/tiny_ast/` are superseded |
| 2026-06-01 | Study is now a **four-paradigm** comparison (was three) | Supervised (CNN) · metric (ProtoNet) · frozen transfer (W2V2-L2) · unsupervised anomaly (Conv-AE / OC-SVM); RQ5 added |
| 2026-06-01 | Preprocessing gains a **16 kHz raw-waveform branch (step 4b)** | wav2vec 2.0 was pretrained at 16 kHz; W2V2-L2 needs native-rate waveform input. MFCC branch renumbered 4b → 4c; Stage 2 reopened to emit waveform shards |
| 2026-06-23 | **Event-based window selection** added for impulsive classes (gunshot, dog) | Blind slicing labelled silent windows of long clips as a threat; event-centred windows (energy onset ≥ 8 dB above clip floor) drop them, reducing weak-label noise and false positives (`select_event_windows`, mirrors `alertrack/audio/onset.py`) |
| 2026-06-24 | Dataset topped up to **11,333 clips** | AudioSet top-up for wind/rain (→ 2,000) and gunshot (→ 3,304); human → 1,242 |
| 2026-06-25 | **Split leakage found and fixed — switched to group-aware split** | File-level split scattered 568 parent recordings across train/test, inflating `threat_gunshot` F1 to 0.999. New group-aware split (`scripts/grouping.py`, `scripts/regenerate_splits.py`) keeps each recording in one split: 0 leaks. Pre-fix model scores are invalid; full re-shard + retrain required. Honest scores are lower but generalise better on-device |
| 2026-06-26 | CNN class weights tempered (raw inverse-freq → sqrt) | Raw inverse-frequency (6.6× spread) stacked on focal-γ over-weighted rare classes; the model over-predicted dog/vehicle (high recall, low precision). sqrt weighting (~2.6× spread) rebalances precision/recall |
| 2026-06-28 | **Anomaly detectors re-selected on validation detection AUC** | Conv-AE/OC-SVM hyperparameters *and* checkpoint now chosen by background-vs-threat val AUC (Optuna for Conv-AE, exhaustive grid for OC-SVM), not a label-free proxy. Conv-AE jumped 0.60 → 0.805 binary AUC and now detects gunshot (AUC 0.839), overtaking OC-SVM (0.719) |
| 2026-06-29 | **All five models trained and evaluated on the leak-free split** | Final test scores: CNN 0.807 macro-F1 (deployed) ≈ ProtoNet 0.804 > W2V2-L2 0.763; Conv-AE 0.805 > OC-SVM 0.719 binary AUC. Full analysis in `MODEL_COMPARISON.md` |
| 2026-06-30 | **USB mic replaced by INMP441 I2S MEMS mic** | Digital I2S removes the mains-hum problem entirely (no analog power path). Captures 48 kHz → resampled to 44.1 kHz; onset/silence gates recalibrated to the quieter floor (`SILENCE_THRESHOLD`/`ONSET_MIN_RMS` 0.01 → 0.0015). Field enclosure (Pi + SIM808) CAD added under `cad/`. Setup: `alertrack/deploy/INMP441_SETUP.md` |

---

## 9. Critical path and blockers

**Current critical path:** Stage 3a (CNN, Kaggle GPU) → Stage 3b (ProtoNet, needs CNN encoder) → Stage 4b (Conv-AE) → Stage 4c (OC-SVM) → Stage 5 (comparative eval) → Stage 6 (deployment). Stage 4a (W2V2-L2) is independent of the CNN and can train in parallel once the 16 kHz waveform shards exist.

**Resolved blockers:**
- ~~`threat_chainsaw` gap~~ — 567 clips, target met
- ~~Stage 2 preprocessing rewrite~~ — mel/mfcc shards on disk

**Active dependencies:**
- Stage 2 must emit the **16 kHz raw-waveform shards (step 4b)** before Stage 4a (W2V2-L2) can extract frozen layer-2 embeddings — new requirement from the updated proposal
- Stage 3b (ProtoNet) cannot start until Stage 3a (CNN) produces `best_model.pt` — encoder weights are shared
- Stage 4b (Conv-AE) trains independently on background-class audio; unlocks learnability filter (step 6e) for a future preprocessing re-run
- DIR calibration (step 5) is optional and de-prioritised — the INMP441 I2S mic resolved the mains-hum problem that originally motivated tighter device calibration; a `--dir-ir` re-run with the new mic remains a possible future refinement, not a blocker

**Hardware:** All components deployed. Pi at `alertreck.local`, SSH accessible. INMP441 I2S mic wired to GPIO and captured via ALSA; SIM808 on the hardware UART (`/dev/ttyAMA0`); 32 GB SD and Rwanda SIM confirmed. Field enclosure (Pi + SIM808) modelled in `cad/`.

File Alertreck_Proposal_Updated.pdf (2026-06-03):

Alertreck: Offline Edge AI for Anti-Poaching Acoustic Surveillance: Benchmarking Pretrained Embeddings, Metric Learning, Supervised Classification, and Anomaly Detection on Identical Field Hardware

BSc in Software Engineering (Machine Learning)

Orpheus Mhizha Manga

Supervisor: Hubert Apana

Date: May 2026

### DECLARATION

I, Orpheus Mhizha Manga, declare that this project proposal is my original work and has not been submitted for academic credit at this or any other institution. All sources of information consulted during its preparation have been appropriately acknowledged and cited in accordance with applicable academic referencing standards. The system design, comparative experimental framework, and supporting documentation are the result of my own research and engineering effort under the supervision of Hubert Apana at the African Leadership University.

Signature: Orpheus Mhizha Manga

Date: May 2026

### TABLE OF CONTENTS

DECLARATION | 2
TABLE OF CONTENTS | 3
LIST OF TABLES | 4
LIST OF FIGURES | 5
LIST OF ACRONYMS AND ABBREVIATIONS | 6
ABSTRACT | 8
CHAPTER ONE: INTRODUCTION | 9
1.1 Introduction and Background | 9
1.2 Problem Statement | 10
1.3 Project’s Main Objective | 11
1.3.1 List of Specific Objectives | 11
1.4 Research Questions | 12
1.5 Project Scope | 13
1.6 Significance and Justification | 13
1.7 Research Budget | 14
1.8 Research Timeline | 15
CHAPTER TWO: LITERATURE REVIEW | 17
2.1 Introduction | 17
2.2 Overview of Existing Systems | 17
2.3 Review of Related Work | 18
2.3.1 AI in Conservation: Strategic Imperatives | 18
2.3.2 Methodological Foundations of Passive Acoustic Monitoring | 19
2.3.3 Metric Learning and Prototypical Networks for Audio | 19

2.3.4 Audio Transformer Architectures and the Case Against Fine-Tuning Them on Edge 20

2.3.5 Frozen Out-of-Species Transfer with Self-Supervised Embeddings | 20
2.3.6 Anti-Poaching Acoustic Monitoring in African Ecosystems | 21
2.4 Summary of Reviewed Literature | 23

2.5 Strengths and Weaknesses of Existing Systems | 25
2.6 Research Gap and Conclusion | 25
CHAPTER THREE: RESEARCH METHODOLOGY | 27
3.1 Introduction | 27
3.2 Research Design | 27
3.3 Dataset Description | 28
3.3.1 Curriculum Training Schedule | 31
3.4 System Architecture | 33
3.5 System Design | 35
3.5.1 Five-Model Architecture | 35
3.5.2 Evaluation Framework | 37
3.5.3 UML and Design Artefacts | 37
3.6 Development Tools | 43
3.7 Ethical Considerations | 44
REFERENCES | 46

### LIST OF TABLES

Table 1: Seven-Class Acoustic Threat Taxonomy

Table 2: Dataset Sources, Licences, and Acquisition Status

Table 3: Preprocessing and Compound Augmentation Pipeline Summary

Table 4: Five-Model Architecture Comparison Across Four Learning Paradigms

Table 5: Curriculum Training Schedule Across Three Difficulty Phases

Table 6: Summary of Reviewed Literature

Table 7: Functional Requirements

Table 8: Non-Functional Requirements

Table 9: Hardware Bill of Materials and Research Budget

Table 10: Development Tools and Technologies

Table 11: Ten-Week Implementation Timeline

### LIST OF FIGURES

Figure 1: Alertreck System Architecture Four Hardware and Software Layers

Figure 2: Six-Step Audio Processing Pipeline Audio Capture to GPS-Tagged SMS Delivery

Figure 3: Use Case Diagram Field Ranger, System Administrator, and Automated System

Figure 4: Class Diagram Alertreck Software Component Architecture

Figure 5: Entity Relationship Diagram Alertreck SQLite Local Event Database Schema

Figure 6: Sequence Diagram Acoustic Event Detection to GPS-Tagged SMS Delivery

LIST OF ACRONYMS AND ABBREVIATIONS

AI | Artificial Intelligence
AST | Audio Spectrogram Transformer
AUC-ROC | Area Under the Receiver Operating Characteristic Curve
CNN | Convolutional Neural Network
Conv-AE | Convolutional Autoencoder
DCASE | Detection and Classification of Acoustic Scenes and Events
DDR | Design and Development Research
DOA | Direction of Arrival
DSP | Digital Signal Processing
Edge AI | Artificial Intelligence deployed on local edge computing devices
ESC-50 | Environmental Sound Classification Dataset (50 classes)
GPS | Generalised Cross-Correlation with Phase Transform
GSM | Global System for Mobile Communications
HMM | Hidden Markov Model
INT8 | 8-bit Integer (quantization precision)
IoT | Internet of Things
GPS fix time | GPS fix accuracy
MFCC | Mel-Frequency Cepstral Coefficients
ML | Machine Learning
OC-SVM | One-Class Support Vector Machine
PAM | Passive Acoustic Monitoring
PAWS | Protection Assistant for Wildlife Security
ProtoNet | Prototypical Network
RAM | Random Access Memory

RFCx | Rainforest Connection
SDG | Sustainable Development Goal
SMS | Short Message Service
SNR | Signal-to-Noise Ratio
SVM | Support Vector Machine
GPS NMEA fix | Time Difference of Arrival
TFLite | TensorFlow Lite
UAV | Unmanned Aerial Vehicle
UNODC | United Nations Office on Drugs and Crime
VAD | Voice Activity Detection
XAI | Explainable Artificial Intelligence

### ABSTRACT

Wildlife poaching across African savannah ecosystems continues to devastate biodiversity, with between 10,000 and 15,000 elephants killed annually and ranger coverage standing at just one per 72 km² far below what effective surveillance requires (Waldron et al., 2022; Elephanatics Foundation, 2024). Existing solutions fail in the field. Rainforest Connection requires a 50 Kbps continuous uplink, rendering it non-functional across most remote African parks (Lynam et al., 2025), while AudioMoth operates offline but delivers no real-time alerts, leaving threats unresponded to until physical device retrieval. This project designs, develops, and evaluates Alertreck: a fully offline edge AI acoustic monitoring system running on a Raspberry Pi 4 Model B (2 GB RAM) with a single USB microphone and a SIM808 GSM/GPS module, built specifically for remote conservation environments with no internet access.

The research conducts a formal four-paradigm comparative study currently unaddressed in the anti-poaching acoustic literature, benchmarking supervised multi-class classification via a Convolutional Neural Network, metric learning via Prototypical Networks, frozen out-of-species transfer via a truncated wav2vec 2.0 (layer-2) embedding with a lightweight linear head, and unsupervised anomaly detection via a Convolutional Autoencoder with a One-Class SVM baseline. All five models are trained on a seven-class acoustic dataset of 8,648 clips assembled from ESC-50, AudioSet, UrbanSound8K, Mozilla Common Voice, and Freefield1010, and evaluated on identical hardware under a common nine-technique framework targeting AUC-ROC above 0.85 and per-class F1 above 0.80. The winning model is deployed with TensorFlow Lite INT8 quantisation and Grad-CAM explainability, delivering GPS-tagged SMS alerts including precise coordinates acquired from the SIM808 via AT command to rangers within 30 seconds at under USD 80 hardware cost. It is hypothesised that the out-of-species embedding paradigm will generalise most reliably across all seven classes, building on Geldenhuys and Niesler (2026), who recently demonstrated that this approach matches supervised performance for elephant vocalisations without any fine-tuning.

### CHAPTER ONE: INTRODUCTION

### 1.1 Introduction and Background

Wildlife conservation across Africa is confronting a structural technological deficit with real and measurable consequences. The African elephant population has declined from approximately 1.3 million individuals in 1979 to around 500,000 today, a reduction of more than 60 percent driven primarily by poaching for ivory (Elephanatics Foundation, 2024). Between 10,000 and 15,000 elephants continue to be killed by poachers every year, and the IUCN now classifies savanna elephants as Endangered and forest elephants as Critically Endangered (IUCN, 2021). The United Nations Office on Drugs and Crime published its third World Wildlife Crime Report in 2024, documenting illegal trade affecting more than 4,000 animal and plant species across 162 countries between 2015 and 2021, and concluding that wildlife trafficking has not been substantially reduced in two decades of concerted international action despite an estimated annual criminal revenue of USD 20 billion (UNODC, 2024).

The operational challenge facing conservation rangers is principally one of spatial coverage. A peer-reviewed study published in Nature Sustainability in 2022 established that the current global ranger coverage density stands at one ranger per 72 km², far below the minimum required for effective protection of most threatened ecosystems (Waldron et al., 2022). African Parks, the largest NGO managing African protected areas, employs 2,119 rangers to protect 20 million hectares across 22 parks, approximately one ranger per 94 km² (African Parks, 2024). Akagera National Park in Rwanda, the primary design reference for this project, spans 1,122 km² and has undergone significant biodiversity recovery following renewed investment in conservation infrastructure; however, its borders and internal zones present coverage challenges consistent with the wider continental pattern. Poaching operations exploit these coverage gaps deliberately and systematically, operating at night, in dense vegetation, and at the known intervals between patrol routes.

Passive Acoustic Monitoring (PAM) offers a genuinely complementary capability to traditional visual monitoring. Sound propagates through dense vegetation and operates independently of lighting conditions, allowing a gunshot, a running chainsaw, or an approaching vehicle engine to be detected hundreds of metres from its source. Contemporary AI-based PAM systems have demonstrated reliable acoustic threat detection where connectivity is available; however, all currently deployed real-time acoustic monitoring systems depend on continuous internet or cellular data connectivity for cloud-based inference connectivity that is unavailable across the majority of remote African national parks (Lynam et al., 2025). This project builds Alertreck: a fully offline edge AI acoustic monitoring system that classifies seven threat categories, identifies the specific threat class with a confidence score, appends GPS device coordinates from the SIM808 receiver, and delivers a labelled, GPS-tagged SMS alert to a ranger’s mobile phone within 30 seconds with no internet required at any stage.

### 1.2 Problem Statement

The core problem is not that rangers lack information, it is that they receive it too late, from too few locations, and only after a threat has already materialised. The closest existing solution, Rainforest Connection (RFCx), uses repurposed Android devices to stream audio to cloud-based convolutional neural network servers for near-real-time classification. Field deployments in Cameroon, Borneo, and the Amazon have produced documented detections of illegal activity (Lynam et al., 2025). However, the RFCx Guardian’s own technical documentation specifies a minimum continuous data uplink of 50 Kbps for its core classification function (RFCx, 2023). In environments such as Kafue National Park in Zambia covering 22,000 km² with an estimated 4,000 to 6,000 active poachers operating inside its boundaries, reliable cellular data coverage does not exist across the majority of the park. RFCx is therefore architecturally non-functional in precisely the environments where acoustic monitoring is most urgently needed.

The second problem is that offline alternatives lack operational alert delivery. AudioMoth (Hill et al., 2019), a low-cost open-source recorder priced at approximately USD 50, performs on-device event classification using Hidden Markov Model classifiers without requiring internet connectivity. However, when AudioMoth detects a gunshot or chainsaw, the detection is stored on the device’s memory card and remains there until a ranger physically retrieves the device which may occur hours or days after the event. A threat that is detected but not communicated within a response window of minutes provides no operational value. Furthermore, AudioMoth relies on pre-programmed acoustic templates that limit generalisation to novel threat sounds and provide no classification of what type of threat was detected.

The third problem is the absence of any system that combines offline classification with explainable alerts and labelled location context. Existing systems either classify without location (AudioMoth, RFCx) or provide spatial information only through commercial infrastructure requiring significant cost and connectivity (ShotSpotter). Rangers who receive automated alerts from black-box systems frequently distrust them, contributing to alarm fatigue and reduced response rates (Lynam et al., 2025; Campos et al., 2019). Alertreck addresses all three gaps simultaneously: it operates entirely offline, delivers real-time GPS-tagged SMS alerts within 30 seconds via GSM cellular, and provides Grad-CAM spectrogram overlays that show rangers exactly which acoustic feature triggered each classification at a hardware cost under USD 80.

A fourth and methodologically critical problem is the absence of empirical guidance on which machine learning paradigm best serves anti-poaching acoustic detection under the dual constraints of limited labelled African data and severe domain shift between training corpora and field deployment. Annotated bioacoustic data are notoriously scarce: training a fully supervised deep network on African gunshot or chainsaw recordings is impractical because such recordings do not exist at the scale supervised learning requires. Geldenhuys and Niesler (2026) recently established that pretrained acoustic embeddings classify elephant vocalisations at performance approaching that of end-to-end supervised neural networks without any fine-tuning of the embedding model and that the second layer of wav2vec 2.0 retains sufficient information for effective elephant call classification while preserving only approximately 10 percent of the full network’s parameters. Their result was demonstrated on bioacoustic calls only. Alertreck extends this finding to a multi-class taxonomy that includes non-biological threats (gunshots, chainsaws, vehicles) and benchmarks it directly against supervised, metric-learning, and unsupervised paradigms on identical edge hardware.

### 1.3 Project’s Main Objective

This project aims to design, develop, and evaluate Alertreck, a low-cost, fully offline edge AI acoustic monitoring system for remote African conservation environments where no internet connectivity is available.

The core research conducts a formal four-paradigm comparative study, benchmarking supervised classification, metric learning, frozen out-of-species transfer, and unsupervised anomaly detection to determine which learning paradigm most reliably identifies specific poaching-related acoustic threats on identical edge hardware.

Beyond model selection, the project integrates SIM808 GPS coordinate tagging and Grad-CAM explainability into the deployed system, evaluating whether GPS-tagged SMS alerts including precise device coordinates can be consistently delivered to rangers within the 30-second operational response constraint.

### 1.3.1 List of Specific Objectives

1. To review academic and applied literature on AI in conservation, passive acoustic monitoring, metric learning, frozen out-of-species transfer with self-supervised embeddings, and compound acoustic augmentation; to assemble and standardise a seven-class acoustic dataset of at least 8,000 clips from publicly available sources; and to produce identical train, validation, and test splits for all five model architectures, ensuring a reproducible experimental baseline.
2. To develop and implement Alertreck’s five-model comparative architecture comprising a Convolutional Neural Network, a Prototypical Network, a truncated wav2vec 2.0 (layer-2) frozen embedding with a lightweight linear classifier head, a Convolutional Autoencoder, and a One-Class SVM across four learning paradigms; and to integrate the winning model with TensorFlow Lite INT8 quantisation, Grad-CAM explainability, SIM808 GSM/GPS alert delivery with device coordinates appended to every SMS, and a Flask LAN dashboard on a Raspberry Pi 4 (2 GB RAM) prototype assembly.
3. To evaluate system performance across nine measurable techniques targeting AUC-ROC above 0.85, per-class F1 score above 0.80, false-positive rate below 20 percent, end-to-end SMS alert latency under 30 seconds, continuous power consumption at or below 5 watts, GPS coordinates successfully appended to every alert via SIM808 AT+CGNSINF, and prototype hardware cost at or below USD 80; and to produce a formal four-paradigm comparative results table providing reproducible empirical guidance for conservation deployment decisions.

### 1.4 Research Questions

RQ1. Which learning paradigm supervised multi-class classification, metric learning via prototypical networks, frozen out-of-species transfer, or unsupervised anomaly detection achieves the highest AUC-ROC, per-class F1 score, and lowest false-positive rate when classifying seven-class African savannah acoustic threat data on identical edge hardware?

RQ2. How does per-class detection performance differ across the five models at signal-to-noise ratios of 5, 10, and 20 dB, and which sound class poses the greatest detection challenge under field-representative interference conditions?

RQ3. Can the SIM808 GSM/GPS module acquire a GPS fix and successfully append device coordinates to a labelled SMS alert within the 30-second end-to-end latency constraint, and what is the typical GPS fix acquisition time under outdoor field conditions?

RQ4. Do Grad-CAM heatmaps applied to the winning model’s mel-spectrogram inputs highlight time-frequency regions that correspond to the acoustically expected features of each threat class, providing interpretable explanations that support conservation ranger trust in the system?

RQ5. Does the out-of-species embedding advantage demonstrated by Geldenhuys and Niesler (2026) for biological vocalisations specifically, that a truncated, frozen wav2vec 2.0 layer-2 embedding approaches end-to-end supervised performance for elephant calls extend to non-biological acoustic threats (gunshots, chainsaws, and vehicles) in a multi-class African savannah dataset, and does it retain that advantage on edge hardware after INT8 quantisation?

### 1.5 Project Scope

Alertreck encompasses the design, development, prototype assembly, and performance evaluation of an edge AI acoustic monitoring system for remote African savannah conservation environments, tested using a controlled acoustic testbed replicating the infrastructure constraints of deployment parks. The acoustic taxonomy covers seven sound classes: background_animals (non-threat wildlife), background_wind_rain (weather and natural ambience), threat_gunshot, threat_chainsaw, threat_vehicle, threat_human, and threat_dog. Akagera National Park in Rwanda serves as the primary design reference. Kafue National Park in Zambia, Queen Elizabeth National Park in Uganda, and the Kavango-Zambezi Transfrontier Conservation Area are the primary need-case examples, representing the scale and infrastructure constraints the system is designed to address.

In scope: a seven-class labelled acoustic dataset from publicly available sources; five trained and evaluated model architectures across four learning paradigms; one Raspberry Pi 4 prototype (2 GB RAM) with USB microphone and SIM808 GSM/GPS module; GPS coordinate tagging verified under outdoor conditions; Grad-CAM explainability on the winning model; a Flask LAN dashboard; and a formal nine-technique comparative evaluation study. Explicitly out of scope: multi-species ecological monitoring beyond the seven-class taxonomy; drone or satellite integration; cloud-connected architectures; deployment in an actual national park during the project period; full position triangulation across multiple distributed devices; and large-scale hardware rollout beyond the single prototype unit.

### 1.6 Significance and Justification

Alertreck is significant for a reason that is easy to state and harder to find in most conservation technology research: it is designed to actually work in the places it is meant to be used. The offline-first architecture, the GSM-only communication pathway, and the sub-USD-80 hardware budget are not design compromises; they are the fundamental design premises, derived directly from the infrastructure realities of remote African national parks. Every technical decision in the system is constrained by the question: will this function without an internet connection, in an outdoor African environment?

The project makes four distinct contributions to the field. To the best of the author's knowledge, no prior work has conducted a formal four-paradigm comparative study of supervised classification, metric learning, frozen out-of-species transfer, and unsupervised anomaly detection for African savannah poaching threat sounds on identical data and hardware, providing reproducible empirical guidance for conservation deployment decisions that the field currently lacks. Additionally, the application of prototypical networks to anti-poaching acoustic classification represents an underexplored direction in the literature, directly addressing the documented background/threat spectral confusion problem by optimising explicitly for inter-class separation in the embedding space. Furthermore, the project extends the Geldenhuys and Niesler (2026) out-of-species embedding finding previously demonstrated for bioacoustic vocalisations into a multi-class taxonomy that includes non-biological threats such as gunshots, chainsaws, and vehicles, testing whether the layer-2 wav2vec 2.0 transfer advantage holds when the target domain encompasses both biological and mechanical sounds rather than a single species.

Fourth, the integration of the SIM808’s built-in GPS receiver with offline multi-class acoustic classification transforms point-of-detection alerts into GPS-tagged notifications that tell rangers both what was detected and precisely where the sensor that detected it is located at sub-USD-80 total hardware cost. Grad-CAM explainability for labelled conservation alerts addresses the ranger trust gap identified by Lynam et al. (2025) at an operational depth no existing deployed system provides: rangers can see exactly which acoustic feature in the spectrogram triggered each alert. Beyond the immediate application, the methodology is directly replicable to other keystone species, other ecosystems, and other behavioural monitoring challenges where the signal of interest is deviation from a learned normal.

### 1.7 Research Budget

The table below presents the hardware bill of materials for the Alertreck prototype unit. All components are commercially available from local electronics suppliers in Rwanda or via regional distributors. The prototype targets a total material cost at or below USD 80 for a minimal viable unit.

Component | Specification | Role | Cost (USD)
Raspberry Pi 4 Model B | 2 GB RAM, quad-core ARM Cortex-A72 @ 1.8 GHz | Edge processing audio capture, inference, alert transmission | $53
USB microphone | Plug-and-play, 100 Hz–16 kHz frequency response | Continuous single-channel outdoor audio capture at 44.1 kHz | $8
SIM808 GSM/GPS module | Quad-band 850/900/1800/1900 MHz; built-in GPS receiver; UART serial | Dual-function: GSM for SMS alert delivery + GPS for device coordinates appended to every alert via AT+CGNSINF | $22

Component | Specification | Role | Cost (USD)
SIM card (MTN/Airtel) | Local Rwandan prepaid SIM | Cellular network access for SMS delivery; no data plan required | $2
MicroSD card | 32 GB minimum, Class 10 | OS, model weights, audio logs, SQLite database | $5
Miscellaneous | UART serial cable, USB-A, jumper wires | Hardware assembly and connectivity | $5
TOTAL | | | USD 95

Table 9: Hardware Bill of Materials and Research Budget

### 1.8 Research Timeline

The project is implemented across ten weeks following a Design and Development Research (DDR) methodology. The Gantt chart below presents each phase, its weekly span, and the key deliverables produced.

Phase / Deliverables | W1 | W2 | W3 | W4 | W5 | W6 | W7 | W8 | W9 | W10 +
Phase 1: Data & Preprocessing | █ | █
Phase 2: Supervised & Metric Models | | | █ | █ | █
Phase 3: Frozen transfer and unsupervised detectors (W2V2-L2, Conv-AE, OC-SVM) | | | | | █ | █
Phase 4: Comparative Evaluation | | | | | | | █

Phase 5: Edge Deployment | █
Phase 6: Direction + GSM Integration | █ | █
Phase 7: Grad-CAM, Dashboard & Evaluation | | █ | █
Phase 8: Writing & Submission | | | █

Table 11: Ten-Week Implementation Timeline

### CHAPTER TWO: LITERATURE REVIEW

### 2.1 Introduction

This chapter reviews academic and applied literature relevant to the Alertreck project across seven principal domains: strategic AI in conservation; methodological foundations of Passive Acoustic Monitoring; metric learning and prototypical networks for audio; audio transformer architectures; frozen out-of-species transfer with self-supervised speech embeddings; anti-poaching acoustic monitoring in African ecosystems; and compound acoustic augmentation with curriculum training for robust classification. The search targeted peer-reviewed articles, conference proceedings, and technical reports published between 2015 and 2026 on platforms including Google Scholar, IEEE Xplore, the ACM Digital Library, Frontiers, MDPI Sustainability, arXiv, and the DCASE Challenge proceedings. Approximately forty primary sources were identified and reviewed, of which twenty-eight are directly cited in the proposal. The purpose is not to catalogue every relevant paper but to synthesise the most directly applicable work, compare methodologies and deployment constraints, and identify precisely where the proposed research extends beyond what has been published. The review is structured to map directly onto the five theoretical pillars of the Alertreck conceptual framework: bioacoustics, machine learning across four paradigms, edge computing, explainable AI, and acoustic signal processing.

### 2.2 Overview of Existing Systems

Three deployed systems represent the current state of the art in real-time conservation acoustic monitoring. The Rainforest Connection (RFCx) Guardian uses repurposed Android devices to stream continuous audio to cloud-based convolutional neural network servers, where gunshots and chainsaw sounds are classified in near real time. Field deployments in Cameroon, Borneo, and the Amazon have produced documented detections of illegal logging and poaching activity (Lynam et al., 2025). However, the Guardian’s technical documentation specifies a minimum continuous data uplink of 50 Kbps for its core classification function (RFCx, 2023). Without this uplink, the device records audio but cannot classify it; no alert is ever produced. In Kafue National Park in Zambia, reliable cellular data coverage does not exist across the majority of the park’s 22,000 km². RFCx is architecturally non-functional in precisely the environments where acoustic monitoring is most urgently needed.

The AudioMoth (Hill et al., 2019) is a low-cost open-source recorder priced at approximately USD 50 that performs on-device event classification using pre-programmed Hidden Markov Model classifiers, without internet connectivity. Unlike RFCx, all processing runs locally on the device. However, AudioMoth has a critical operational limitation: it has no alert delivery mechanism. When AudioMoth detects a gunshot or chainsaw, the detection is stored on the device’s memory card and remains there until a ranger physically retrieves the device which may occur hours or days after the event. Furthermore, AudioMoth relies on pre-programmed acoustic templates, limiting generalisation to novel threat sounds and providing no threat class specificity beyond a binary trigger.

The ARBIMON platform enables large-scale remote audio collection through centralised web-based processing infrastructure, designed primarily for ecological analysis rather than operational threat alerting. Like RFCx, it requires continuous connectivity for core processing and provides no real-time ranger alert delivery. EarthRanger aggregates data from multiple sensor types for conservation managers but is not itself a detection system; it depends on external sensors to provide inputs. Camera traps offer a complementary visual detection capability but require line of sight, adequate lighting, and are rendered ineffective by vegetation density and night-time operations.

Together, these systems define the gap that Alertreck occupies. No currently deployed system simultaneously provides offline acoustic threat classification with specific class labelling, GPS-tagged SMS alert delivery with device coordinates, and Grad-CAM explainability to rangers at sub-USD-80 hardware cost.

### 2.3 Review of Related Work

### 2.3.1 AI in Conservation: Strategic Imperatives

Kumar and Jakhar (2022) document how AI addresses the manpower shortages, safety risks, and physical constraints inherent in traditional conservation management by enabling continuous automated surveillance in conditions incompatible with sustained human presence. Isabelle and Westerlund (2022), reviewing AI deployments within the SDG 15 framework, catalogue the

PAWS (Protection Assistant for Wildlife Security) system in Uganda’s Queen Elizabeth National Park, which uses game-theoretic patrol route optimisation to predict poaching locations and direct rangers accordingly, with documented reductions in poaching incidents. A persistent bias in conservation AI research, however, favours visual monitoring approaches. Fergus et al. (2024) evaluate CNN and vision transformer platforms for thermal and optical species detection across multiple continents, noting that they share a fundamental constraint: they require line of sight, are rendered ineffective by vegetation density, and cannot detect acoustic threats. Lynam et al. (2025) identify three specific barriers to widespread PAM deployment: bandwidth requirements for cloud uplinks, power consumption constraints, and ranger trust gaps, all three of which are directly addressed by the Alertreck design.
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

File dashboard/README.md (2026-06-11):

# Alertreck Explainability Dashboard

A Flask LAN dashboard that shows each detected sound with a **Grad-CAM** heatmap overlaid on its
mel spectrogram — visualising *why* the CNN flagged it as a threat.

It runs on a **separate machine** (your Mac), where PyTorch already lives, so the Raspberry Pi stays
ONNX-only and lean. Grad-CAM is computed on the **exact mel spectrogram the Pi classified** (the
`*.mel.npy` sidecar), so the explanation matches the edge model's real decision.

```
Pi (detector) ──saves──►  evidence/<date>/<class>/<name>.wav
                                                  <name>.mel.npy   ← model input
                                                  <name>.json      ← class, probs, GPS, time
      │  rsync  (sync_events.sh)
      ▼
Mac (this app) ──► Grad-CAM (torch, models/custom_cnn/best_model.pt) ──► overlay PNG ──► web page
```
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

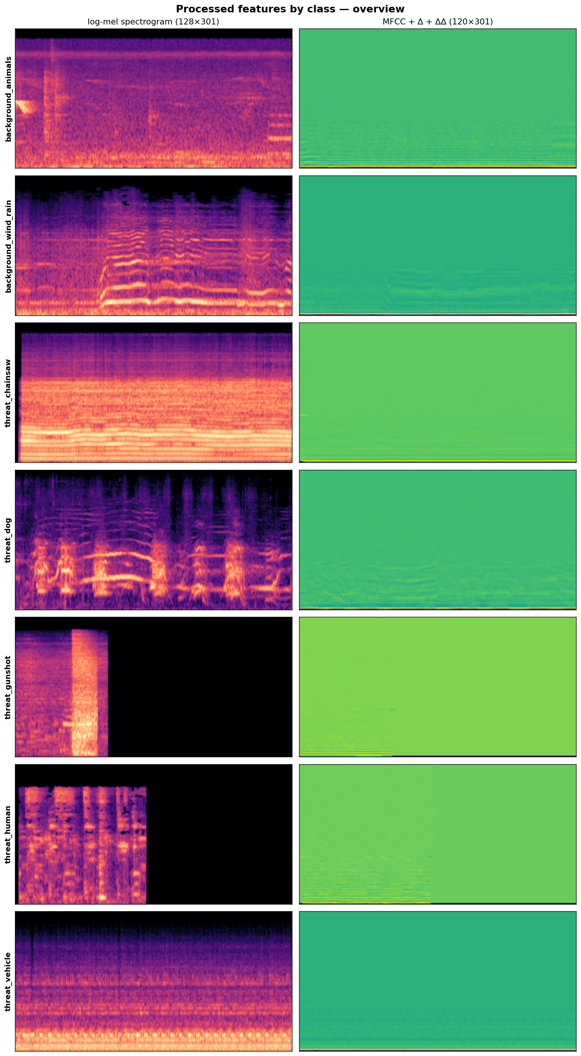
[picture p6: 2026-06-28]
docs/figures/feature_samples/overview_all_classes.png

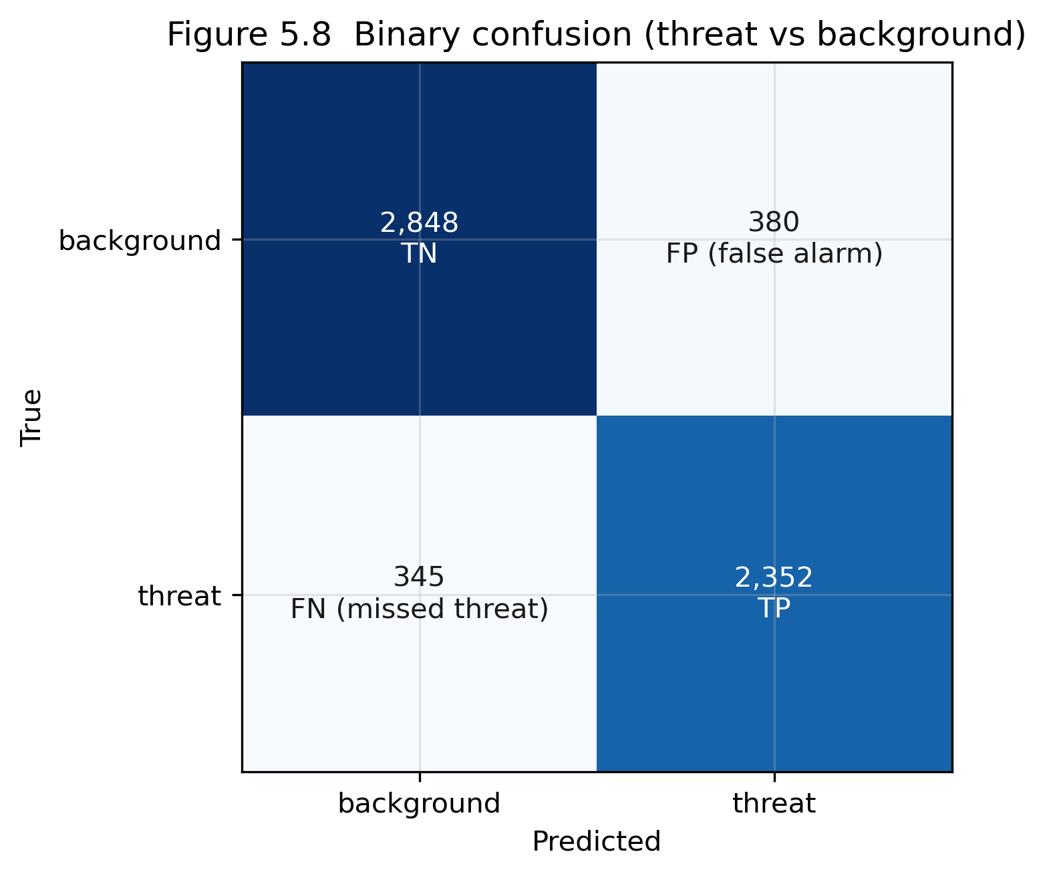
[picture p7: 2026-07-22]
docs/figures/chapter5/fig_5_8_binary_confusion.png

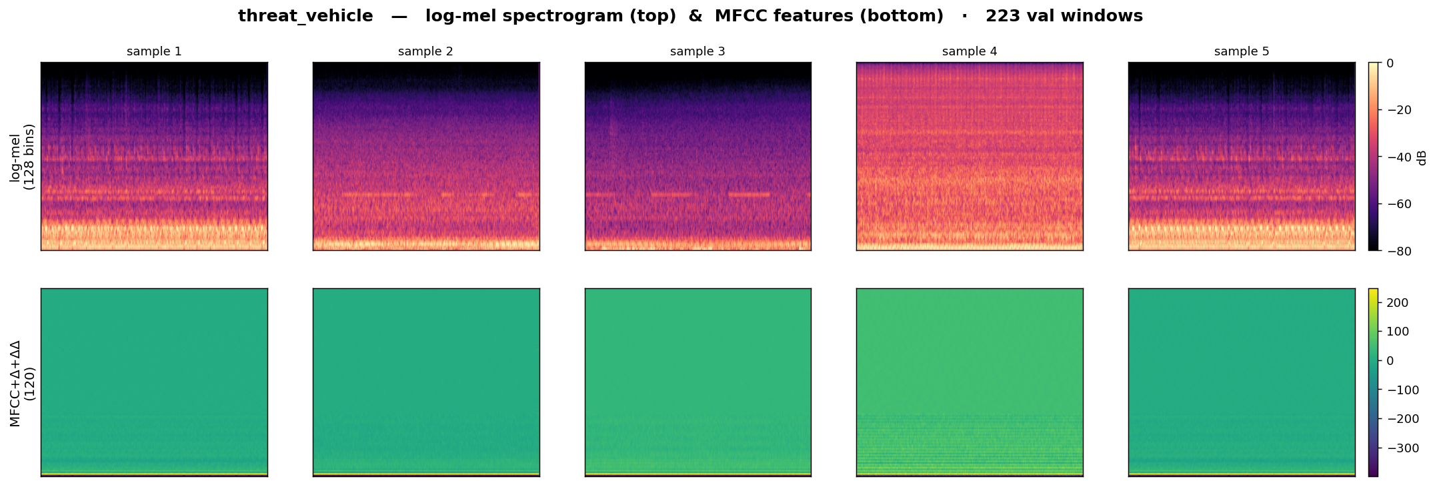
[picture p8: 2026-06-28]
docs/figures/feature_samples/6_threat_vehicle.png

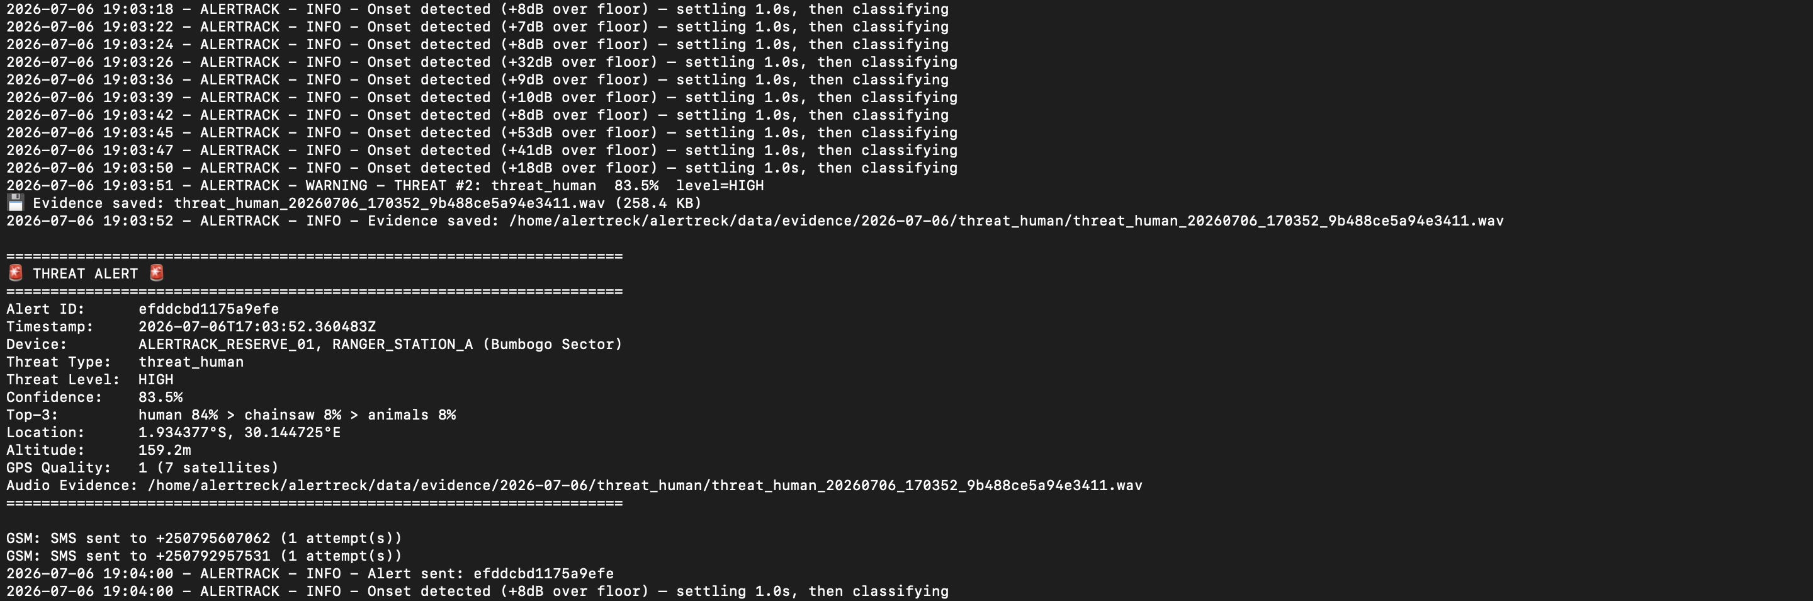
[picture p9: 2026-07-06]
docs/img/live-alert-sms.png

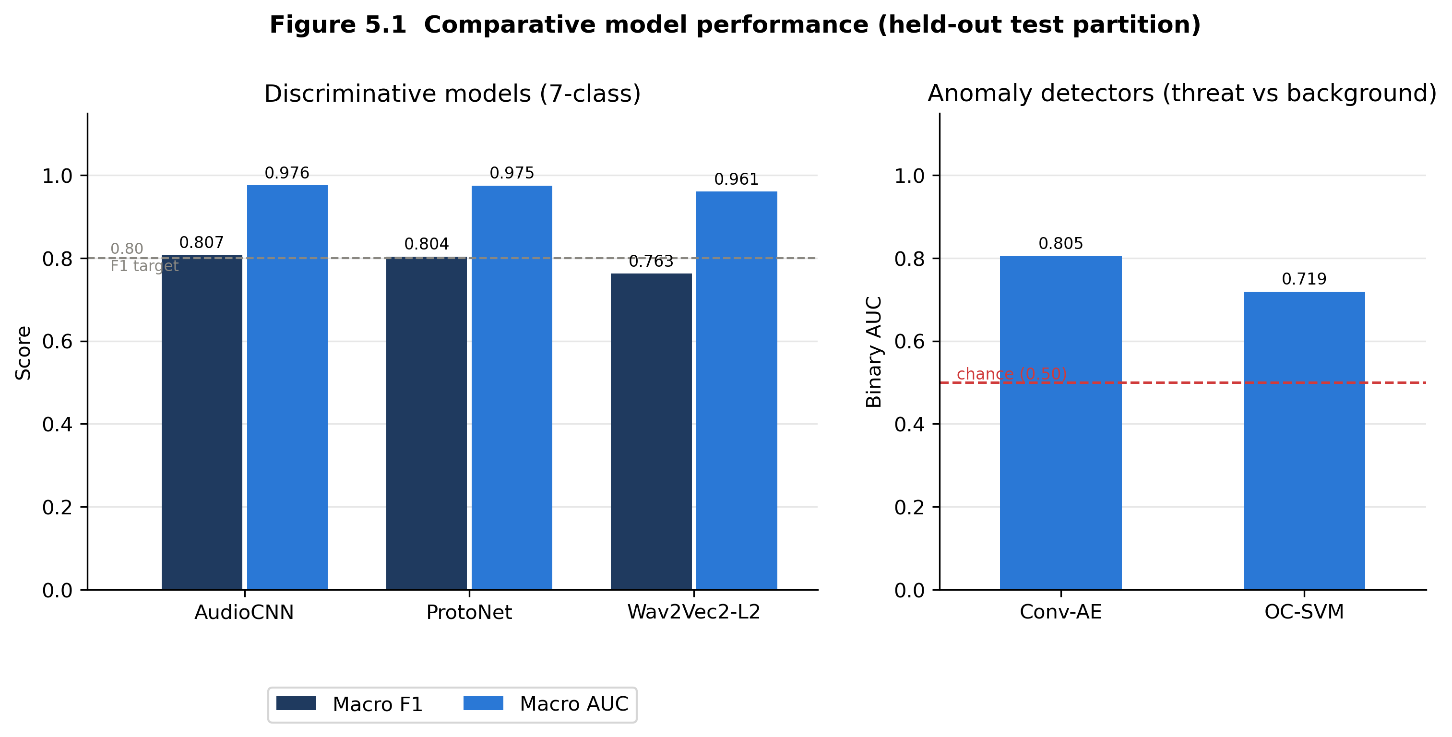
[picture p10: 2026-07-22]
docs/figures/chapter5/fig_5_1_model_comparison.png

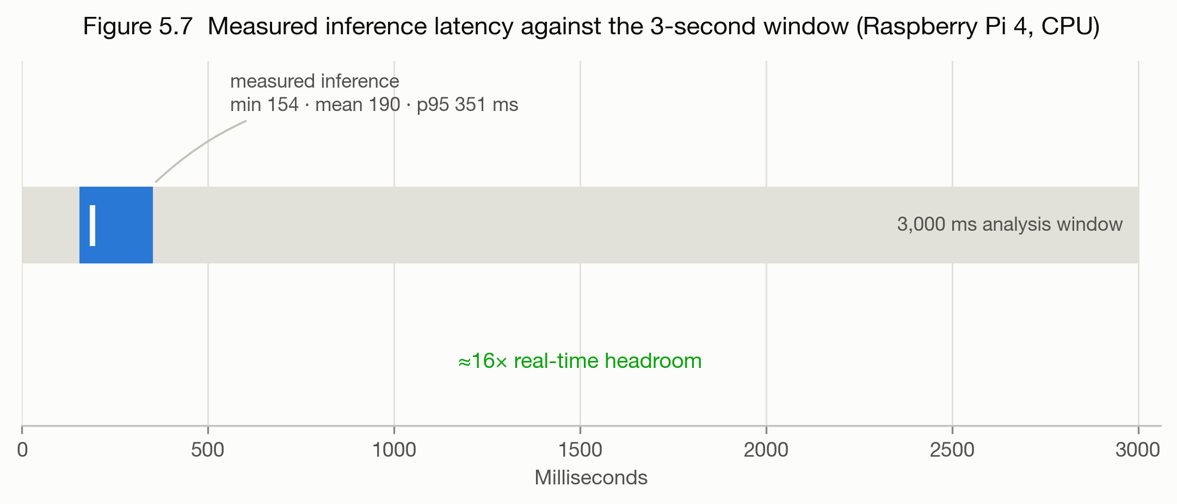
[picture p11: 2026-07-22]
docs/figures/chapter5/fig_5_7_latency.png

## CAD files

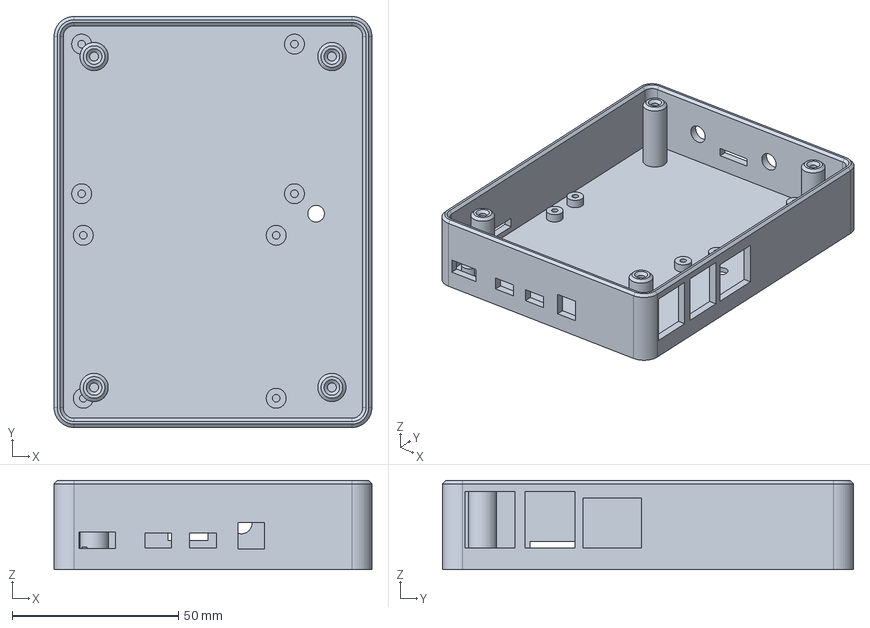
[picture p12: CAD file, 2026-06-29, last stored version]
cad/alertreck_pro_base.step
95.6 x 123.6 x 26.8 mm

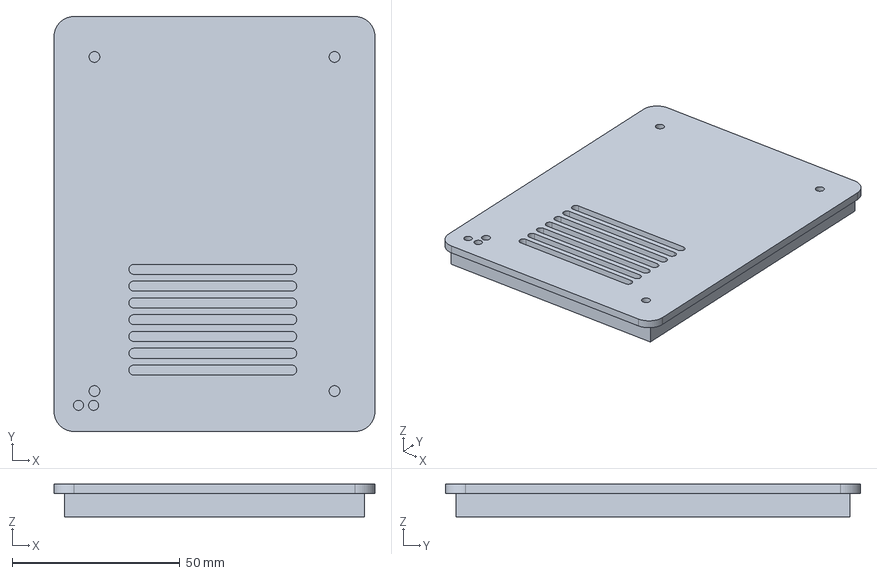
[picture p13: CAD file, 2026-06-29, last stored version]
cad/alertreck_pro_lid.step
95.6 x 123.6 x 9.80 mm

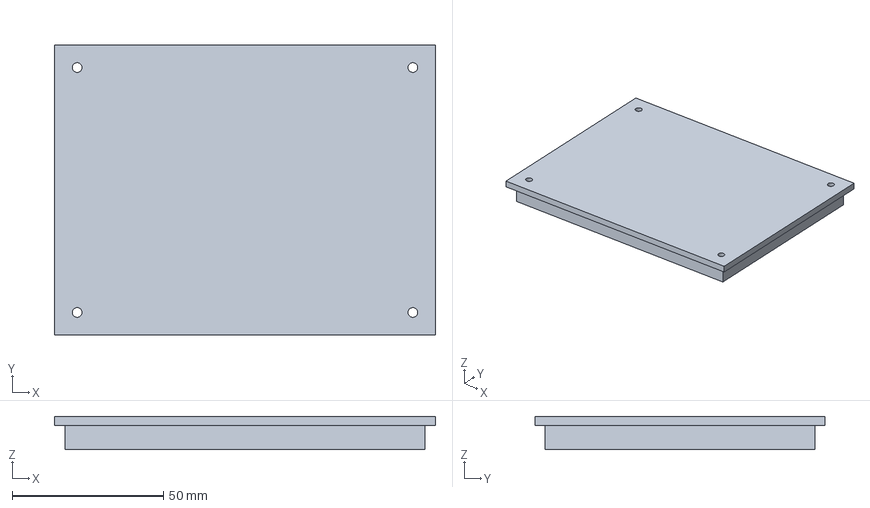
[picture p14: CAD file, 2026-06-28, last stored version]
cad/alertreck_lid.step
126.0 x 96.0 x 11.0 mm

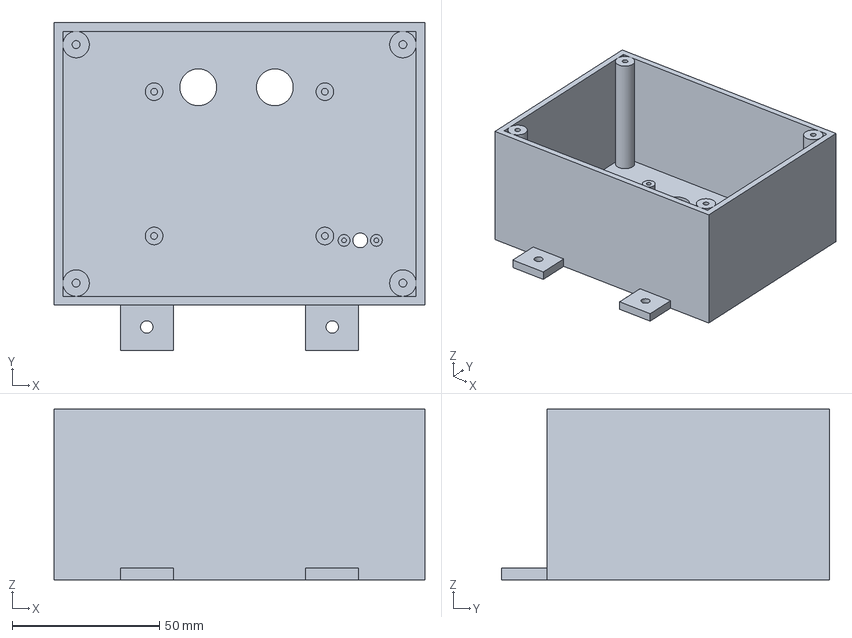
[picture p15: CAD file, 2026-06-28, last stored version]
cad/alertreck_base.step
126.0 x 111.4 x 58.0 mm

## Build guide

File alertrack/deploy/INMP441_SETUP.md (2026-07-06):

# INMP441 I2S Microphone — Setup for Alertreck (Raspberry Pi 4)

Replaces the USB microphone with the **INMP441 I2S MEMS** mic. The INMP441 is a
*digital* mic on the Pi's **I2S** bus — it does **not** show up as a USB audio
device. After this setup it becomes the ALSA **default**, resampled to the model's
44.1 kHz mono, so the daemon needs only `MIC_DEVICE_INDEX = None` (already set).

> ⚠️ **The INMP441 is a 3.3 V device. Never wire VDD to 5 V — it will damage the mic.**

---

## 1. Wiring (INMP441 → Raspberry Pi 40-pin header)

| INMP441 pin | Function | Pi signal (BCM) | Pi physical pin |
|---|---|---|---|
| VDD | Power 3.3 V | 3V3 | **1** |
| GND | Ground | GND | **6** |
| SCK | Bit clock (BCLK)| GPIO18 / PCM_CLK| **12** |
| WS | Word select (LR)| GPIO19 / PCM_FS | **35** |
| SD | Serial data out | GPIO20 / PCM_DIN| **38** |
| L/R | Channel select  | GND → LEFT | **9** (or 14) |

- **L/R → GND** puts the mic on the **left** channel (what `asound.conf` reads).
  Tie it to 3.3 V instead only if you change the routing to the right channel.
- Keep the SCK/WS/SD wires short (< ~15 cm) — I2S is a clocked digital bus.

```
        INMP441                 Raspberry Pi 4 (physical pins)
       ┌─────────┐
   VDD ┤o        │── 3V3  ........ pin 1
   GND ┤o        │── GND  ........ pin 6   (and L/R → pin 9 GND)
   SD  ┤o        │── GPIO20 ...... pin 38
   WS  ┤o        │── GPIO19 ...... pin 35
   SCK ┤o        │── GPIO18 ...... pin 12
   L/R ┤o        │── GND  ........ pin 9
       └─────────┘
```

---

## 1b. Combined wiring — INMP441 (I2S) **and** SIM808 (UART) together

The mic and the SIM808 do **not** share any signal pin. The INMP441 sits on the
Pi's **I2S bus** (GPIO18/19/20); the SIM808 sits on the **UART** (GPIO14/15). The
only thing they share is **ground**, which is required, not a conflict — every GND
pin on the Pi is the same electrical rail, so each device just uses its own.

| Device | Wire | Pi signal | Pi physical pin |
|---|---|---|---|
| INMP441 | VDD  | 3V3 (**3.3 V only**) | **1**  |
| INMP441 | GND  | GND | **6**  |
| INMP441 | L/R  | GND → left channel | **9**  |
| INMP441 | SCK  | GPIO18 / I2S BCLK | **12** |
| INMP441 | WS | GPIO19 / I2S FS | **35** |
| INMP441 | SD | GPIO20 / I2S DIN | **38** |
| SIM808  | RXD  | GPIO14 / TXD | **8**  |
| SIM808  | TXD  | GPIO15 / RXD | **10** |
| SIM808  | GND  | GND (common ground)  | **20** |
| SIM808  | VCC  | **external 5 V ≥2 A supply — NOT the Pi's 5 V** | — |

Signal pins used: mic → **12, 35, 38**; SIM808 → **8, 10**. They never overlap.
(The mic's L/R sits on GND pin 9; the SIM808 uses a *different* GND pin — 20 — so
there is no contention even though both need ground.)

```
Raspberry Pi 4 · 40-pin header (pin 1 = top-left)

 pin 1  [3V3 ]──VDD INMP441          pin 2  [5V ]
 pin 5  [    ]                       pin 6  [GND]──GND INMP441
 pin 7  [    ]                       pin 8  [TXD]──RXD SIM808
 pin 9  [GND ]──L/R INMP441          pin 10 [RXD]──TXD SIM808
 pin 11 [    ]                       pin 12 [I2S CLK ]──SCK INMP441
 pin 13 [    ]                       pin 14 [GND     ]
 pin 19 [    ]                       pin 20 [GND     ]──GND SIM808
   ...                               pin 35 [I2S FS  ]──WS  INMP441
                                     pin 38 [I2S DATA]──SD  INMP441
```

**Three things that actually matter (not the pin numbers):**

1. **SIM808 VCC → external 5 V ≥2 A supply, never the Pi's 5 V pin.** The GSM radio
   pulls ~2 A bursts when transmitting; powering it from the Pi browns out and
   reboots the Pi mid-alert. Wire only the SIM808's TX, RX, and GND to the Pi, and
   connect the external supply's ground to a Pi GND (pin 20 above = common ground).
2. **INMP441 is 3.3 V only** — VDD to pin 1 (3V3), never a 5 V pin.
3. **UART is crossed, not straight:** SIM808 **TXD → Pi pin 10 (RXD)**, SIM808
   **RXD → Pi pin 8 (TXD)**. If SMS/GPS returns nothing, swap these two first — it is
   the most common cause.

**Boot config for both buses at once** (`/boot/firmware/config.txt`) — all four lines
coexist because I2S and UART are separate peripherals:

```
dtparam=i2s=on
dtoverlay=googlevoicehat-soundcard
enable_uart=1
dtoverlay=disable-bt
```

Then free the UART for the SIM808: `sudo systemctl disable hciuart` and reboot. The
SIM808 comes up on `/dev/ttyAMA0` at 9600 baud, matching `SIM808_PORT` in `config.py`.

---

## 2. Enable I2S + the soundcard overlay

Edit the boot config (Bookworm: `/boot/firmware/config.txt`; older OS: `/boot/config.txt`):

```bash
sudo nano /boot/firmware/config.txt
```

Add (or uncomment) these lines, then save:

```
dtparam=i2s=on
dtoverlay=googlevoicehat-soundcard
```

The `googlevoicehat-soundcard` overlay is the standard, well-tested way to expose
an INMP441 as an ALSA capture card. Reboot:

```bash
sudo reboot
```

After reboot, confirm the card exists:

```bash
arecord -l
# expect a card named "sndrpigooglevoi" (snd_rpi_googlevoicehat_soundcard)
```

---

## 3. Make it the default mic (resample + downmix)

Install the provided ALSA config so any app gets the mic at the rate/channels it asks for:

```bash
sudo cp alertrack/deploy/asound.conf /etc/asound.conf
sudo alsactl kill quit 2>/dev/null; sudo alsa force-reload 2>/dev/null || true
```

(If `arecord -l` showed a card name other than `sndrpigooglevoi`, edit
`/etc/asound.conf` to match before copying.)

---

## 4. Test the mic

Raw ALSA capture (clap/speak during the 5 s, then play it back):

```bash
arecord -D default -f S16_LE -r 44100 -c 1 -d 5 /tmp/mic.wav
aplay /tmp/mic.wav
```

Then the Alertreck-level test (captures at 44.1 kHz mono like the daemon):

```bash
python3 alertrack/deploy/test_i2s_mic.py
```

A working mic shows `peak`/`rms` clearly rising when you make noise and near-zero
on silence. **The absolute level is low** (INMP441 is a quiet mic) — that's normal;
the daemon's EBU-R128 loudness normalisation scales it before the model sees it.

---

## 5. Run the daemon

No code change needed beyond `MIC_DEVICE_INDEX = None` (already set in `config.py`).

```bash
python3 -m alertrack.main
```

If you prefer not to override the system default, set in `config.py`
`MIC_DEVICE_INDEX = "alertreck_mic"` and skip the `pcm.!default` part of
`asound.conf` (keep only the `pcm.alertreck_mic` block).

---

## 6. Notes & troubleshooting

- **No analog hum.** Unlike the USB mic, I2S is digital, so there's no 50/60 Hz
  mains hum. The `HPF_ENABLED` high-pass in `config.py` is now mostly redundant —
  leave it on (harmless, removes wind rumble) or set `HPF_ENABLED = False` and
  compare field detections.
- **Silent capture (peak ≈ 0):** re-check L/R → GND, the SD/WS/SCK pins, and that
  `arecord -l` lists the card (overlay loaded). Loose SD wire is the usual cause.
- **`arecord` works but Python is silent:** PortAudio is opening the wrong device.
  Set `MIC_DEVICE_INDEX = "googlevoicehat"` (name substring) in `config.py`.
- **Card name differs / overlay not found:** some images use a different overlay;
  alternatively follow Adafruit's "I2S MEMS microphone" custom-overlay guide, then
  point `asound.conf`/`MIC_DEVICE_INDEX` at that card.
- **Sample rate:** the mic runs 48 kHz natively; `plug` resamples to the 44.1 kHz
  the models were trained on. Do **not** change `SAMPLE_RATE` in `config.py`.

---

## 7. Field enclosure (stacked Pi 4 + SIM808)

A weatherproof, FDM-printable enclosure that stacks the Pi 4 (lower) and SIM808 EVB
(upper) is generated parametrically:

```bash
/Library/Frameworks/Python.framework/Versions/3.12/bin/python3.12 \
    cad/alertreck_stack_enclosure.py
```

Outputs to `cad/`: `alertreck_stack_body.{stl,step}`, `alertreck_stack_lid.{stl,step}`,
`alertreck_stack_sim_door.stl`. Internal cavity 100×70×65 mm, 3 mm walls / 4 mm floor.

- **Standoffs:** Pi on 4× M2.5 posts **7 mm** tall (58×49 pattern); SIM808 on 4×
  corner posts to **Z=37 mm** (10 mm above the Pi top), kept just outside the Pi
  footprint so they don't foul the board.
- **Antennas:** two 8 mm SMA bulkhead holes (GSM + GPS) on the **+X wall** (Face 2,
  upper zone, beside the Pi USB/Ethernet); plus an 8 mm GPS port in the **lid centre**
  for a sky-facing patch antenna.
- **SIM access:** sliding door on the **+Y wall** (Face 4, `sim_card_door.stl`),
  openable from outside without removing the lid.
- **Wiring note:** the INMP441 (I2S) and SIM808 (UART) wire to the GPIO header
  internally per §1b — the box needs **no** USB port for the mic. The Pi USB-A
  cutouts remain for service access only.
- **PETG print settings:** 0.2 mm layer, 4 perimeters, 30 % gyroid infill, body
  printed open-face-up. See the header of `cad/alertreck_stack_enclosure.py` for the
  full face map and the design notes.

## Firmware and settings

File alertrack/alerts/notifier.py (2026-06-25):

"""
Alert Notifier Module
======================
Generates and dispatches alerts via console, disk, and SIM808 GSM SMS.
SMS payload: ALERTRECK | <class> | Conf: x% | GPS: lat,lon | HH:MM
"""

import json
import time
from datetime import datetime, timezone
from typing import Dict, Any, Optional
from pathlib import Path

from ..config import (
    ALERTS_DIR, DEVICE_ID, DEVICE_LOCATION,
    NOTIFY_CONSOLE, NOTIFY_LORA, NOTIFY_GSM, NOTIFY_SATELLITE,
    SIM808_PORT, SIM808_BAUDRATE, SIM808_TIMEOUT,
    RANGER_PHONE_NUMBERS, SMS_MAX_RETRIES, SMS_RETRY_DELAY,
)
from ..utils import get_timestamp, generate_alert_id, save_json, format_confidence, format_coords

try:
    import serial
    _SERIAL_AVAILABLE = True
except ImportError:
    _SERIAL_AVAILABLE = False


def _short_label(class_name: str) -> str:
    """Drop the threat_/background_ prefix for compact SMS display."""
    return class_name.split("_", 1)[-1] if "_" in class_name else class_name


def _format_top_predictions(top_predictions, sep: str = " > ") -> str:
    """'gunshot 92% > human 5% > vehicle 2%' for SMS/console."""
    return sep.join(
        f"{_short_label(p['class'])} {int(round(p['confidence'] * 100))}%"
        for p in top_predictions
    )


def _sim808_at(ser, cmd: str, expected: str = "OK", timeout: float = 5.0) -> bool:
    """Send one AT command and wait for expected response."""
    ser.write((cmd + "\r\n").encode())
    deadline = time.time() + timeout
    buf = ""
    while time.time() < deadline:
        chunk = ser.read(ser.in_waiting or 1).decode("ascii", errors="ignore")
        buf += chunk
        if expected in buf:
            return True
        if "ERROR" in buf:
            return False
    return False


def _sim808_send_sms(number: str, text: str,
                     port: str, baudrate: int, timeout: float) -> bool:
    """Send one SMS via SIM808 AT commands. Returns True on success."""
    with serial.Serial(port, baudrate, timeout=2.0) as ser:
        time.sleep(0.5)
        if not _sim808_at(ser, "AT"):
            raise RuntimeError("SIM808 not responding to AT")
        if not _sim808_at(ser, "AT+CMGF=1"):   # text mode
            raise RuntimeError("Could not set SMS text mode")
        ser.write(f'AT+CMGS="{number}"\r'.encode())
        time.sleep(0.5)
        buf = ser.read(ser.in_waiting or 1).decode("ascii", errors="ignore")
        if ">" not in buf:
            raise RuntimeError("No SMS prompt received")
        ser.write(text.encode() + bytes([26]))   # message + Ctrl-Z
        deadline = time.time() + timeout
        buf = ""
        while time.time() < deadline:
            chunk = ser.read(ser.in_waiting or 1).decode("ascii", errors="ignore")
            buf += chunk
            if "+CMGS:" in buf:
                return True
            if "ERROR" in buf:
                return False
        return False


class AlertNotifier:
    """
    Manages alert generation and notification dispatch.
    """
    
    def __init__(self):
        """Initialize alert notifier."""
        self.device_id = DEVICE_ID
        self.device_location = DEVICE_LOCATION
        self.alerts_sent = 0
        
        # Ensure alerts directory exists
        ALERTS_DIR.mkdir(parents=True, exist_ok=True)
        
        print(f"AlertNotifier initialized:")
        print(f"  Device ID: {self.device_id}")
        print(f"  Location: {self.device_location}")
        print(f"  Console: {NOTIFY_CONSOLE}")
        print(f"  LoRaWAN: {NOTIFY_LORA}")
        print(f"  GSM: {NOTIFY_GSM}")
        print(f"  Satellite: {NOTIFY_SATELLITE}")
    
    def create_alert(
        self,
        threat_info: Dict[str, Any],
        location: Dict[str, Any],
        audio_path: str = None
    ) -> Dict[str, Any]:
        """
        Create alert object from threat detection.
        
        Args:
            threat_info: Threat information from decision engine
            location: GPS location data
            audio_path: Path to saved audio evidence
            
        Returns:
            Complete alert dictionary
        """
        alert = {
            # Alert metadata
            'alert_id': generate_alert_id(),
            'timestamp': get_timestamp(),
            'device_id': self.device_id,
            'device_location': self.device_location,
            
            # Threat information
            'threat_type': threat_info['threat_type'],
            'threat_level': threat_info['threat_level'],
            'confidence': threat_info['confidence'],
            'top_predictions': threat_info.get('top_predictions', []),
            'class_probabilities': threat_info['class_probabilities'],
            
            # Location
            'latitude': location.get('latitude', 'UNKNOWN'),
            'longitude': location.get('longitude', 'UNKNOWN'),
            'altitude': location.get('altitude', 'UNKNOWN'),
            'gps_quality': location.get('fix_quality', 0),
            'gps_satellites': location.get('satellites', 0),
            
            # Evidence
            'audio_evidence': audio_path,
            
            # Status
            'status': 'PENDING',  # PENDING, ACKNOWLEDGED, RESOLVED
            'notified_channels': []
        }
        
        return alert
    
    def send_alert(self, alert: Dict[str, Any]) -> bool:
        """
        Send alert through all enabled notification channels.
        
        Args:
            alert: Alert dictionary
            
        Returns:
            True if at least one channel succeeded
        """
        success = False
        
        # Save alert to disk (always)
        if self._save_alert_to_disk(alert):
            alert['notified_channels'].append('DISK')
            success = True
        
        # Console notification
        if NOTIFY_CONSOLE:
            if self._notify_console(alert):
                alert['notified_channels'].append('CONSOLE')
                success = True
        
        # LoRaWAN notification (stub)
        if NOTIFY_LORA:
            if self._notify_lora(alert):
                alert['notified_channels'].append('LORA')
                success = True
        
        # GSM notification (stub)
        if NOTIFY_GSM:
            if self._notify_gsm(alert):
                alert['notified_channels'].append('GSM')
                success = True
        
        # Satellite notification (stub)
        if NOTIFY_SATELLITE:
            if self._notify_satellite(alert):
                alert['notified_channels'].append('SATELLITE')
                success = True
        
        if success:
            self.alerts_sent += 1
        
        return success
    
    def _save_alert_to_disk(self, alert: Dict[str, Any]) -> bool:
        """Save alert as JSON file."""
        try:
            filename = f"{alert['alert_id']}_{alert['timestamp'][:10]}.json"
            filepath = ALERTS_DIR / filename
            
            return save_json(alert, filepath)
        
        except Exception as e:
            print(f"❌ Failed to save alert to disk: {e}")
            return False
    
    def _notify_console(self, alert: Dict[str, Any]) -> bool:
        """Print alert to console."""
        try:
            print("\n" + "=" * 70)
            print("🚨 THREAT ALERT 🚨")
            print("=" * 70)
            print(f"Alert ID:      {alert['alert_id']}")
            print(f"Timestamp:     {alert['timestamp']}")
            print(f"Device:        {alert['device_id']} ({alert['device_location']})")
            print(f"Threat Type:   {alert['threat_type']}")
            print(f"Threat Level:  {alert['threat_level']}")
            print(f"Confidence:    {format_confidence(alert['confidence'])}")
            if alert.get('top_predictions'):
                print(f"Top-3:         {_format_top_predictions(alert['top_predictions'])}")
            
            # Location
            lat = alert['latitude']
            lon = alert['longitude']
            if lat != 'UNKNOWN' and lon != 'UNKNOWN':
                print(f"Location:      {format_coords(lat, lon)}")
                print(f"Altitude:      {alert['altitude']}m")
                print(f"GPS Quality:   {alert['gps_quality']} ({alert['gps_satellites']} satellites)")
            else:
                print(f"Location:      UNKNOWN (GPS unavailable)")
            
            # Evidence
            if alert['audio_evidence']:
                print(f"Audio Evidence: {alert['audio_evidence']}")
            
            print("=" * 70)
            print()
            
            return True
        
        except Exception as e:
            print(f"❌ Console notification failed: {e}")
            return False
    
    def _notify_lora(self, alert: Dict[str, Any]) -> bool:
        """
        Send alert via LoRaWAN.
        
        STUB IMPLEMENTATION - To be completed with actual LoRaWAN hardware.
        
        For real implementation:
        - Use LoRaWAN module (e.g., RFM95W)
        - Encode alert as compact payload
        - Send to LoRaWAN gateway
        - Handle acknowledgments
        """
        print(f"📡 [LoRaWAN STUB] Would send alert {alert['alert_id']}")
        
        # Simulate success for testing
        return True
    
    def _notify_gsm(self, alert: Dict[str, Any]) -> bool:
        """Send SMS alert via SIM808 GSM module using AT commands."""
        if not RANGER_PHONE_NUMBERS:
            print("GSM: no ranger phone numbers configured in config.py")
            return False

        lat  = alert.get("latitude",  "?")
        lon  = alert.get("longitude", "?")
        hhmm = datetime.now(timezone.utc).strftime("%H:%M")
        gps_str = f"{lat:.5f},{lon:.5f}" if isinstance(lat, float) else "no fix"

        # Send the top-3 ranked predictions so rangers can gauge certainty and
        # spot likely false positives. Falls back to the single class if absent.
        top = alert.get("top_predictions")
        if top:
            ranked = _format_top_predictions(top)
        else:
            ranked = f"{_short_label(alert['threat_type'])} {int(alert['confidence'] * 100)}%"
        sms = f"ALERTRECK | {ranked} | GPS: {gps_str} | {hhmm}"

        if not _SERIAL_AVAILABLE:
            print(f"GSM: pyserial not installed — would send: {sms}")
            return False

        success = False
        for number in RANGER_PHONE_NUMBERS:
            for attempt in range(1, SMS_MAX_RETRIES + 1):
                try:
                    if _sim808_send_sms(number, sms, SIM808_PORT,
                                        SIM808_BAUDRATE, SIM808_TIMEOUT):
                        print(f"GSM: SMS sent to {number} ({attempt} attempt(s))")
                        success = True
                        break
                except Exception as exc:
                    print(f"GSM: attempt {attempt} failed — {exc}")
                if attempt < SMS_MAX_RETRIES:
                    time.sleep(SMS_RETRY_DELAY)
            else:
                print(f"GSM: all {SMS_MAX_RETRIES} attempts failed for {number}")
        return success
    
    def _notify_satellite(self, alert: Dict[str, Any]) -> bool:
        """
        Send alert via satellite communication.
        
        STUB IMPLEMENTATION - To be completed with actual satellite modem.
        
        For real implementation:
        - Use satellite modem (e.g., Iridium, Globalstar)
        - Send short burst data (SBD)
        - Optimize payload size (very limited bandwidth)
        - Handle retries and timeouts
        """
        print(f"🛰️  [Satellite STUB] Would send alert {alert['alert_id']}")
        
        # Simulate success for testing
        return True
    
    def get_stats(self) -> Dict:
        """Get notifier statistics."""
        return {
            'alerts_sent': self.alerts_sent,
            'console_enabled': NOTIFY_CONSOLE,
            'lora_enabled': NOTIFY_LORA,
            'gsm_enabled': NOTIFY_GSM,
            'satellite_enabled': NOTIFY_SATELLITE
        }


def test_notifier():
    """Test the alert notifier."""
    print("\n🔔 Testing AlertNotifier...")
    print("=" * 60)
    
    # Create notifier
    notifier = AlertNotifier()
    
    # Create test alert
    threat_info = {
        'threat_type': 'THREAT',
        'threat_level': 'HIGH',
        'confidence': 0.92,
        'class_probabilities': {
            'BACKGROUND': 0.03,
            'THREAT_CONTEXT': 0.05,
            'THREAT': 0.92
        }
    }
    
    location = {
        'latitude': -1.373333,
        'longitude': 36.857782,
        'altitude': 1700.0,
        'fix_quality': 1,
        'satellites': 8
    }
    
    audio_path = "/data/evidence/2024-12-29/gunshot_20241229_143022.wav"
    
    # Create alert
    alert = notifier.create_alert(threat_info, location, audio_path)
    
    print("\n📋 Created Alert:")
    print(json.dumps(alert, indent=2))
    
    # Send alert
    print("\n📤 Sending alert...")
    success = notifier.send_alert(alert)
    
    print(f"\nAlert sent: {success}")
    print(f"Notified channels: {alert['notified_channels']}")
    
    # Show stats
    print("\n📊 Notifier Statistics:")
    stats = notifier.get_stats()
    for key, value in stats.items():
        print(f"  {key}: {value}")
    
    print("\n" + "=" * 60)
    print("✅ Test complete!")


if __name__ == "__main__":
    test_notifier()

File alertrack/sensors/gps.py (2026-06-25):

"""
GPS Module
==========
Reads GPS coordinates from the SIM808 GSM/GPRS/GPS module via UART serial.

SIM808 setup (run once after power-on):
  AT+CGNSPWR=1    — power on built-in GPS
  AT+CGNSOUT=1    — stream NMEA sentences ($GPGGA, $GPRMC) on UART

The GPSReader class parses those NMEA sentences directly.
Alternative: use SIM808AT.get_location() which polls AT+CGNSINF instead.
"""

import time
from typing import Optional, Tuple, Dict
import threading

try:
    import serial
    SERIAL_AVAILABLE = True
except ImportError:
    SERIAL_AVAILABLE = False
    print("⚠️  pyserial not available - GPS will be simulated")

from ..config import (
    GPS_ENABLED, GPS_PORT, GPS_BAUDRATE, GPS_TIMEOUT,
    GPS_RECONNECT_DELAY, SIMULATE_GPS, DEBUG_MODE
)


class GPSReader:
    """
    Reads GPS coordinates from NMEA-compliant GPS module.
    Supports UART and USB GPS devices.
    """
    
    def __init__(self, port: str = None, baudrate: int = None):
        """
        Initialize GPS reader.
        
        Args:
            port: Serial port (e.g., '/dev/ttyUSB0')
            baudrate: Baud rate (typically 9600 or 4800)
        """
        self.port = port or GPS_PORT
        self.baudrate = baudrate or GPS_BAUDRATE
        self.timeout = GPS_TIMEOUT
        
        self.serial_port = None
        self.is_running = False
        self.read_thread = None
        
        # Latest GPS data
        self.lock = threading.Lock()
        self.latitude = None
        self.longitude = None
        self.altitude = None
        self.timestamp = None
        self.fix_quality = 0
        self.num_satellites = 0
        
        # Statistics
        self.total_reads = 0
        self.successful_reads = 0
        self.failed_reads = 0
        
        if SIMULATE_GPS:
            print("🌍 GPS simulation mode enabled")
            self._simulate_gps_data()
        elif not GPS_ENABLED:
            print("🌍 GPS disabled in config")
        elif not SERIAL_AVAILABLE:
            print("🌍 pyserial not available - using simulated GPS")
            self._simulate_gps_data()
        else:
            print(f"🌍 GPS initialized: {self.port} @ {self.baudrate} baud")
    
    def start(self):
        """Start GPS reading in background thread."""
        if not GPS_ENABLED or SIMULATE_GPS or not SERIAL_AVAILABLE:
            return
        
        if self.is_running:
            print("⚠️  GPS already running")
            return
        
        self.is_running = True
        self.read_thread = threading.Thread(target=self._read_loop, daemon=True)
        self.read_thread.start()
        print("✅ GPS reading started")
    
    def stop(self):
        """Stop GPS reading."""
        if not self.is_running:
            return
        
        self.is_running = False
        
        if self.read_thread:
            self.read_thread.join(timeout=2.0)
        
        if self.serial_port:
            try:
                self.serial_port.close()
            except:
                pass
            self.serial_port = None
        
        print("🛑 GPS reading stopped")
    
    def _read_loop(self):
        """Main GPS reading loop - runs in background thread."""
        while self.is_running:
            try:
                self._open_port()
                self._read_gps_data()
            except Exception as e:
                print(f"❌ GPS error: {e}")
                print(f"Reconnecting in {GPS_RECONNECT_DELAY}s...")
                time.sleep(GPS_RECONNECT_DELAY)
            finally:
                if self.serial_port:
                    try:
                        self.serial_port.close()
                    except:
                        pass
                    self.serial_port = None
    
    def _open_port(self):
        """Open serial port."""
        if self.serial_port:
            return
        
        try:
            self.serial_port = serial.Serial(
                port=self.port,
                baudrate=self.baudrate,
                timeout=self.timeout
            )
            
            if DEBUG_MODE:
                print(f"📡 GPS port opened: {self.port}")
        
        except Exception as e:
            print(f"❌ Failed to open GPS port: {e}")
            raise
    
    def _read_gps_data(self):
        """Read and parse NMEA sentences."""
        while self.is_running and self.serial_port:
            try:
                # Read line from GPS
                line = self.serial_port.readline().decode('ascii', errors='ignore').strip()
                
                if not line:
                    continue
                
                self.total_reads += 1
                
                # Parse NMEA sentence
                if line.startswith('$GPGGA') or line.startswith('$GNGGA'):
                    # Global Positioning System Fix Data
                    self._parse_gga(line)
                elif line.startswith('$GPRMC') or line.startswith('$GNRMC'):
                    # Recommended Minimum Specific GPS/Transit Data
                    self._parse_rmc(line)
                
            except Exception as e:
                if DEBUG_MODE:
                    print(f"Error reading GPS data: {e}")
                self.failed_reads += 1
                continue
    
    def _parse_gga(self, sentence: str):
        """
        Parse GGA sentence: Global Positioning System Fix Data.
        Format: $GPGGA,time,lat,N/S,lon,E/W,quality,satellites,hdop,altitude,M,...
        """
        try:
            parts = sentence.split(',')
            
            if len(parts) < 10:
                return
            
            # Fix quality (0=invalid, 1=GPS, 2=DGPS)
            fix_quality = int(parts[6]) if parts[6] else 0
            
            if fix_quality == 0:
                return  # No valid fix
            
            # Latitude
            lat_str = parts[2]
            lat_dir = parts[3]
            if lat_str and lat_dir:
                lat = self._convert_to_degrees(lat_str, lat_dir)
            else:
                return
            
            # Longitude
            lon_str = parts[4]
            lon_dir = parts[5]
            if lon_str and lon_dir:
                lon = self._convert_to_degrees(lon_str, lon_dir)
            else:
                return
            
            # Altitude
            alt = float(parts[9]) if parts[9] else None
            
            # Number of satellites
            num_sats = int(parts[7]) if parts[7] else 0
            
            # Update stored data
            with self.lock:
                self.latitude = lat
                self.longitude = lon
                self.altitude = alt
                self.fix_quality = fix_quality
                self.num_satellites = num_sats
                self.timestamp = time.time()
            
            self.successful_reads += 1
            
            if DEBUG_MODE:
                print(f"GPS: {lat:.6f}, {lon:.6f}, alt={alt}m, sats={num_sats}")
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

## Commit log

2025-12-28 Initial commit: AlertReck threat detection system with YAMNet and custom CNN notebooks
    [class_labels_indices.csv]
2026-01-03 Reorganize project structure: move scripts to subdirectories, add alertrack service, and update models
    [class_labels_indices.csv]
2026-05-27 feat: Add documentation, training pipelines, and audio extraction scripts:
    [class_labels_indices.csv, ff1010bird_metadata_2018.csv]
2026-06-07 Updated file structure and added new notebook for training OC-SVM model.
    [class_labels_indices.csv, ff1010bird_metadata_2018.csv]
2026-06-28 added the alertreck enclosure and lid CAD files, added a script to visualize features, and updated the documentation with new figures and information about audio preprocessing and the roadmap.
    [alertreck_base.step, alertreck_lid.step]
2026-06-29 New deployment on raspberry pi with INMP441 I2S microphone. Updated CAD files for new enclosure design. Updated notebooks for training and deployment.
    [alertreck_base.step, alertreck_lid.step, alertreck_pro_base.step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]
2026-07-06 Add capstone deliverable, fix I2S mic capture and dashboard GPS crash
    README: add Capstone Final Deliverable section (testing results,
    analysis, discussion, recommendations) and refresh dataset counts
    to current totals (11,333 files).
    alertrack: set MIC_DEVICE_INDEX for the INMP441 I2S mic so PortAudio
    opens the right ALSA device instead of returning silent zeros.
    dashboard: guard GPS lat/lon rendering with `is number` so events
    with 'UNKNOWN' location no longer 500 the index page.
    Also: add docs/img screenshot assets, drop superseded pro-enclosure
    CAD files, and update docs + training notebooks.
    [alertreck_pro_base.step, alertreck_pro_lid.step]
2026-07-07 updated gitignore to ignore cad folder

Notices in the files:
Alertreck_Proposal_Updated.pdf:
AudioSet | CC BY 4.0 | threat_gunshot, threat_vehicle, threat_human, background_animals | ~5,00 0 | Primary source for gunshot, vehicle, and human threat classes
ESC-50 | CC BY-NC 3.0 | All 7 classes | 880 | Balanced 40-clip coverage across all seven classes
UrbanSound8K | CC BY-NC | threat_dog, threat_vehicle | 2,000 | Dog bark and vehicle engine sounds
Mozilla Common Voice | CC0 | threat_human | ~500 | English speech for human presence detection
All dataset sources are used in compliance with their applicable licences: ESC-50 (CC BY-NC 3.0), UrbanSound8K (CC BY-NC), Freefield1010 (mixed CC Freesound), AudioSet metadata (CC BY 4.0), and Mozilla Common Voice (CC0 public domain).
